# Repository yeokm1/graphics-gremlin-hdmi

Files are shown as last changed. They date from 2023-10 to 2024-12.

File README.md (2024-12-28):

# Graphics Gremlin HDMI

This is a modified version of the Graphics Gremlin ISA CGA/MDA graphics card to include a HDMI port. This is still based on the same Lattice ICE40HX4K FPGA.

(A production run has been made for this board. You can contact explit[at]mailbox[dot]org if you wish to purchase a unit.)

The latest revision now displays CGA colour 6 brown correctly. Since this project builds on the original project, it carries over some emulation inaccuracies in demos like 8088MPH and other applications.

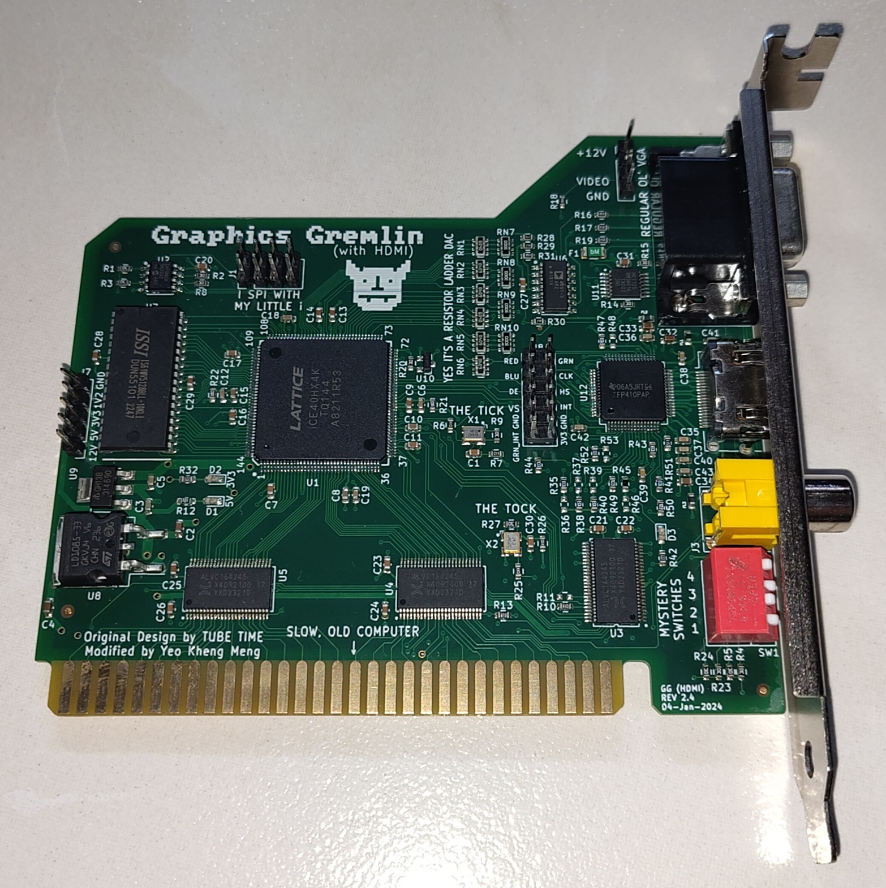
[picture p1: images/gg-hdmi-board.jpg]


Top view of board including the metal bracket.

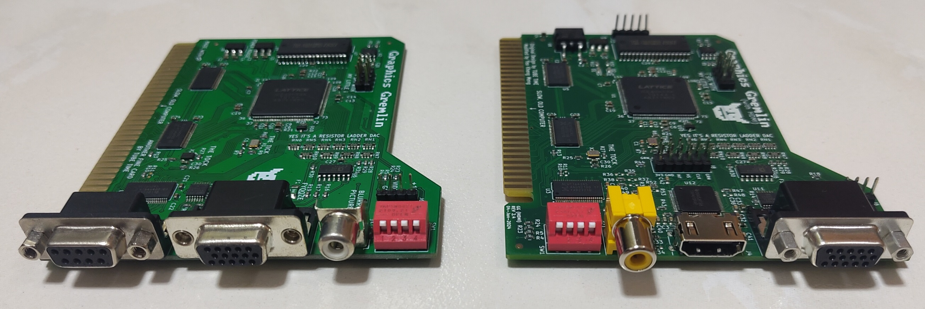
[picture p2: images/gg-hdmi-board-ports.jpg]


Left is the original Graphics Gremlin, right is my modified design.

# Demo videos

* Bootup and CGA compatibility tester (Brown fixed): https://www.youtube.com/watch?v=Ap-goSkkSUI
* Bootup and CGA compatibility tester (Deprecated): https://www.youtube.com/watch?v=xLy6on_o4YM
* 8088MPH: https://www.youtube.com/watch?v=WLpNmEhdTe4
* Area5150 (using CGA overscan): https://www.youtube.com/watch?v=9wYU6qMWlpE
* My talk on this project: https://www.youtube.com/watch?v=r_GiEIe_oZk

# Changes from original project

* Hardware changes
    * Added HDMI port by removing the RGBI DE9 port. Port positions adjusted to ease trace routing.
    * Added [TI TFP410](https://www.ti.com/product/TFP410) DVI transmitter (HDMI is compatible with DVI). HDMI is independent of the VGA/Composite output.
    * Test points for inputs to DVI transmitter.
    * Replaced the 3.3VDC 1A linear regulator with 3A as TFP410 is power hungry at up to 1A.
    * Added pin headers for power.
    * Added LED power indicators for 5V and 3.3V.
    * 2-layer -> 4-layer board to ease routing.
* HDL code changes
    * Selectable MDA colours (HDMI only)
    * Removed normal MDA bitstream as there is no more RGBI port.
    * Added CGA 70Hz mode.
    * Added CGA 60Hz overscan mode for demo and debug purposes.
    * Modified Scandoubler code to support Display Enable signal as required by DVI chip but not VGA.

Readme of the original Graphics Gremlin project can be found [here](original_README.md).

# How to replicate this board and use it?

1. [Fabrication guidelines](https://github.com/yeokm1/graphics-gremlin-hdmi/wiki/Fabrication-guidelines)

2. [Flashing FPGA bitstream](https://github.com/yeokm1/graphics-gremlin-hdmi/wiki/Flashing-bitstream)

3. [Testing the board](https://github.com/yeokm1/graphics-gremlin-hdmi/wiki/Testing-procedures)

4. Usage guide below:

# Switches position

## Switches 1 and 2 for MDA

These colours are applicable for the HDMI section only. 

| 1 | 2 | MDA colour |
|---|---|---|
| open | open | Green |
| open | closed | Yellow |
| closed | open | White |
| closed | closed | Red |



Sample of the different colours when testing the card on my [486 PC](https://github.com/yeokm1/retro-configs/tree/master/desktops/generic-486-pc).

## Switches 1 and 2 for CGA

| Switch | CGA |
|---|---|
| 1 | closed=composite mode. open=VGA mode |
| 2 | closed=thin font. open=normal font |

**Note that VGA and Composite cannot be used simultaneously.** No change from original Graphics Gremlin. HDMI will work on all modes.

## Switches 3 and 4

| 3 | 4 | Bitstream | Function |
|---|---|---|---|
| open | open | Bitstream 0 | MDA 70Hz |
| open | closed | Bitstream 1 | CGA 70Hz |
| closed | open | Bitstream 2 | CGA 60Hz |
| closed | closed | Bitstream 3 | CGA 60Hz with overscan |

### CGA 60 and 70Hz 
After internal scandoubling, the CGA 60Hz will produce a 640x400x60Hz output suitable for most VGA monitors. While this works for the HDMI LCD monitors I have tested, it is technically below the DVI specification of a minimum of 640x480x60Hz and 25.175Mhz pixel clock. 

To meet the specification in case some monitors insist, I have added another mode CGA 70Hz which will produce 640x400 at 70Hz. (Actually 71Hz due to precision limitations of clock multiplying) This 70Hz is however not compatible with composite displays including the one inside IBM5155.

### CGA 60Hz with overscan

The CGA overscan bitstream will show the overscan sections beyond the usual display area just short of Hsync and Vsync. Overscan is used in some demos like Area 5150. However not all HDMI monitors can accept this signal and/or display this properly.

I notice that while a monitor may initially accept this mode, tendency is it will randomly throw you display errors later.

**The purpose of this mode is just for debug and demo purposes**.

# Development info

## Directory structure

```
|-- fab: Gerbers, BOM and PDF schematic
|-- images: Images used in this repo
|-- isa-video: Kicad Design files
|-- verilog: Updated Verilog code to support HDMI
    | -- release: Bitstreams
|-- vga_display_status: Vivado project to process ICE40 FPGA output to DVI transmiter that runs on my Mimas A7 FPGA board.
|-- 3d-bracket: Step and STL file for a 3D-printable bracket
```

## Verilog Toolchain

To compile the project, I used the following open source tool-chain on my Ubuntu running on WSL on Windows 11.

```bash
sudo apt install libftdi-dev cmake

sudo apt install build-essential libboost-system-dev libboost-thread-dev libboost-program-options-dev libboost-test-dev libboost-filesystem-dev libboost-iostreams-dev libeigen3-dev

sudo apt install tclsh clang tcl-dev libreadline-dev bison flex

# Icestorm
git clone https://github.com/YosysHQ/icestorm.git icestorm
cd icestorm
make -j$(nproc)
sudo make install
cd ..

# NextPNR
git clone https://github.com/YosysHQ/nextpnr nextpnr
cd nextpnr
cmake -DARCH=ice40 -DCMAKE_INSTALL_PREFIX=/usr/local .
make -j$(nproc)
sudo make install
cd ..

# Yosys
git clone https://github.com/YosysHQ/yosys.git yosys
cd yosys
git submodule update --init
make -j$(nproc)
sudo make install
```

To program the bitstream to the board, I used `iceprog -p` from OSS CAD Suite. Follow the [flash instructions](https://github.com/yeokm1/graphics-gremlin-hdmi/wiki/Flashing-bitstream). 

## Code compilation

In my Ubuntu WSL:

```bash
cd verilog
mkdir build

# No CGA snow (default)
make

# With CGA snow
make DEFINES="-DCGA_SNOW=1"
```

```bash
# Program without CGA snow bitstream
iceprog -p release\isavideo-20240505-nosnow.binm

# Program with CGA snow bitstream
iceprog -p release\isavideo-20241229-withsnow.binm

# To see verbose output
iceprog -v -p isavideo.binm

# To suppress all output
iceprog -v -p isavideo.binm 2> nul
```

## Special handling for brown colour

The PCB and code treats the palette value "I:0 R:1 G:1 B:0" specially to produce a brown instead of dark yellow as per the CGA standard.

```verilog
// video[1] is the original green value
assign hdmi_grn = video[1] ^ (hdmi_red & video[1] & (hdmi_blu ^ 1) & (hdmi_int ^ 1));
assign hdmi_grn_int = hdmi_int ^ (hdmi_red & video[1] & (hdmi_blu ^ 1) & (hdmi_int ^ 1));
```

This is done using the above boolean logic to lower the green value by using the dedicated hdmi_green_int pin. This logic is [provided by @spbnick](https://github.com/yeokm1/yeokm1.github.io/discussions/115#discussioncomment-7022872).

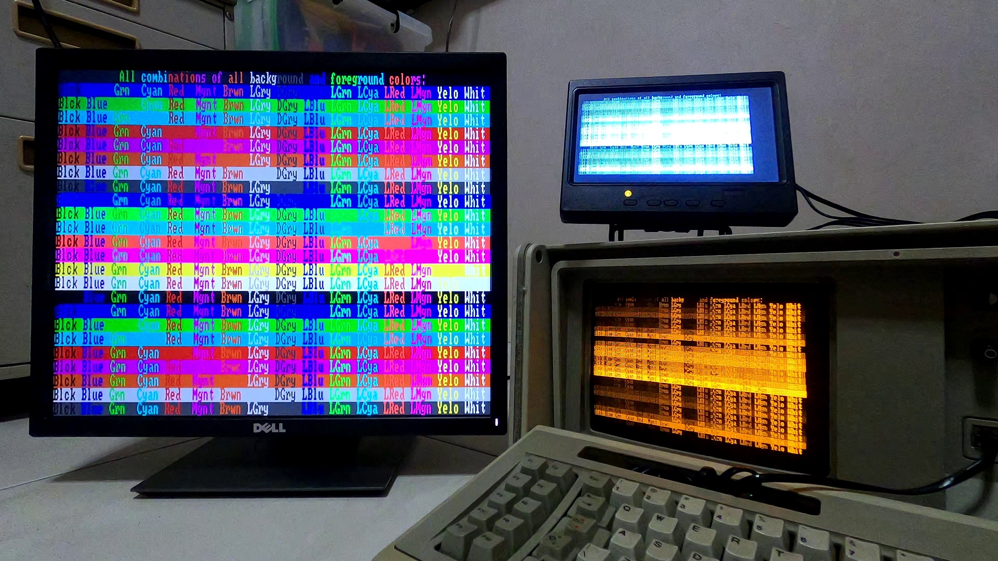
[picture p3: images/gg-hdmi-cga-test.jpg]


My IBM 5155 running the [CGA Compatibility Tester](https://github.com/MobyGamer/CGACompatibilityTester) displaying the colour palatte.

## Testing with Mimas A7 (Xilinx Artix 7)

As part of my testing, I also made a small FPGA test project using another FPGA board Mimas A7 based on the Xilinx Artix 7. 



The FPGA test board reads the raw RGBI, HS, VS, DE and CLK signals that are given to the DVI transmitter and displays the output using its own HDMI output.

The code is heavily based on the [HDMI_FPGA](https://github.com/dominic-meads/HDMI_FPGA/) project by Dominic Meads and runs on Vivado 2023.

## Bitstream Releases
* 20240505 - Disables CGA Snow (Recommended)
* 20241229 - Has CGA Snow. PC/XT systems which are overclocked with tools like [PC Sprint](https://github.com/reeshub/pc-sprint) should use this bitstream. This is due to the higher text mode data being clocked in which will cause artifacts if snow is totally avoided. More info in this [issue #5](https://github.com/yeokm1/graphics-gremlin-hdmi/issues/5).

## Hardware Releases

* 2.1 (9 Aug 2021): Initial release for GG (HDMI)
* 2.2 (17 Sept 2023): Extra Green control line for TFP410
* 2.3 (13 Oct 2023): Corrected VGA port footprint bug
* 2.4 (4 Jan 2024): Kicad 7.10, cleaned up schematic errors, removed unused traces, update pcb symbols and 3D models, cleaned up BOM. (No functional difference with 2.3)

## License
This work is licensed under a Creative Commons Attribution-ShareAlike 4.0
International License. See [https://creativecommons.org/licenses/by-sa/4.0/](https://creativecommons.org/licenses/by-sa/4.0/).

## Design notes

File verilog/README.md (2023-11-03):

# The Graphics Gremlin - FPGA code

(Click here for the [main README](https://github.com/schlae/graphics-gremlin/blob/main/README.md))

The FPGA code is divided into two major sets of files, those for CGA graphics and those for MDA graphics. At some point I'll tidy up and make a nice organized directory tree, but for now they're all in the same place.

* mda\_top.v: The top level file instantiating the MDA graphics logic (Not used as no more RGBI port)
* mda70\_top.v: An alternative top level file for VGA compatible MDA graphics
* mda.v: Implements MDA ISA interface, IO registers and instantiates the CRTC, SRAM interface, sequencer, and pixel engine
* crtc6845.v: This is my mostly-accurate recreation of the old Motorola 6845 CRT controller chip. It generates all the sync timings as well as the character and row addresses. There are probably slight differences between it and the real thing.
* mda\_sequencer.v: Controls timing across the entire card, deciding when to fetch SRAM data, look up character bits from the character ROM, and allow ISA bus access to the SRAM
* mda\_vram.v: Implements the state machine to arbitrate ISA bus and pixel engine access to the video ram (external SRAM)
* mda\_pixel.v: This is the pixel engine. It takes data coming from the SRAM, looks up the pixels in the character ROM, and shifts the data out one pixel at a time. 
* mda\_attrib.v: The attribute generator applies video attributes to the raw pixel data, including brightness, underline, inverse video, blinking. It also applies the blinking cursor.
* mda\_vgaport.v: This module turns the digital MDA video signals into numbers to drive the resistor ladder DAC connected to the VGA port. If you (gasp) dislike amber monochrome monitors, then you can hack this code to make it green or white.
* mda\_hdmiport.v: This module turns the digital MDA video signals to drive the DVI transmitter. Will also adjust the colour based on switch selection.

CGA graphics logic is similar to MDA and shares the same crtc6845.v logic, but the cards are different enough that I couldn't share more.
* cga\_top.v: Instantiates top level CGA logic with 60 Hz refresh rate.
* cga70\_top.v: Instantiates top level CGA logic with 70Hz refresh rate if higher pixel clock is required. (Composite displays are unlikely to work in this mode)
* cga\_overscan\_top.v: Instantiates top level CGA logic with 60Hz refresh rate and show overscan area. (Not all HDMI monitors can accept this)
* cga.v: Implements the ISA bus interface, CGA control registers, wait state generator, and most of the other CGA modules
* cga\_sequencer.v: Generates most of the timing signals used on the card, including memory fetches and pixel engine timing.
* cga\_vram.v: Implements a very basic address MUX for the SRAM interface. This actually causes too much CGA snow, and should be improved using the MDA VRAM interface as a model.
* cga\_pixel.v: The CGA pixel engine takes data from the SRAM, does a character lookup (text mode only), and shifts the data out 1 or 2 bits at a time, depending on the video mode.
* cga\_attrib.v: The attribute generator applies video attributes to the raw pixels data, including color, brightness, and blinking.
* cga\_composite.v: Contains the flip flops used to generate NTSC composite color as well as new sync pulses. The output is a 7-bit signal passed off to the green DAC channel for the RCA jack on the card.
* cga\_scandoubler.v: A very basic scan doubler to convert 15.7KHz CGA video to 31.4KHz VGA video. To save memory, this is done using 4-bit digital RGBI signals.
* cga\_vgaport.v: This module takes RGBI digital video from the scan doubler and turns it into numbers that drive the resistor ladder DAC connected to the VGA port. It produces CGA brown instead of dark yellow.
* cga\_hdmiport.v: This module takes RGBI digital video from the scan doubler to drive the DVI transmitter. It will produce Brown at CGA color #6 by controlling the dedicated Green intensity control pin.

Other miscellaneous files include:
* cga.hex and mda.hex: character ROM
* gremlin.pcf: The pin constraints file that determines what signals are tied to what pins on the FPGA
* isavideo\_t.v: A sloppy test bench that I used to validate and troubleshoot the rest of the logic.
* is61c5128\_t.v: A behavorial Verilog model of the SRAM chip.
* is61\_tester.v: A test bench I used to verify the SRAM chip behavioral model.

## Building

To build the project, you will need to install the tools from [Project IceStorm](http://www.clifford.at/icestorm/) (full instructions are available at that link). The Graphics Gremlin uses NextPNR, so make sure you install that.

Alternatively, you can install the [OSS Cad Suite](https://github.com/YosysHQ/oss-cad-suite-build) which is prebuilt and runs on a variety of platforms.

Once the tools are installed, just navigate to the Graphics Gremlin Verilog directory and run
```
mkdir build
make
```
If you have the FTDI programming cable hooked up to the card, you can also type `make prog`. As a convenience, `make reset` will not program the FPGA but will toggle its reset line which is useful if you change the red switch bank and don't want to cycle power on the host PC.

If the `make prog` command can't find the FTDI programming cable, make sure you have the udev rules set up.

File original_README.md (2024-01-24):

# The Graphics Gremlin - a Retro ISA Video Card

The Graphics Gremlin is an FPGA-based ISA video card specifically designed to emulate certain old video standards. This initial release emulates the original IBM PC monochrome graphics adapter (MDA) as well as the original IBM color graphics adapter (CGA). Since the logic is defined by the bitstream loaded into the FPGA, new emulations may be available in the future to support other video standards.

Graphics Gremlin PCB photo

But why emulate an old video card when they are still fairly easy to find online? Cards aren't hard to find, but monitors that can sync to the unusual frequencies used by MDA (18KHz) and CGA (15KHz) are much harder to find, and these frequencies are rarely supported by modern LCD monitors or video capture hardware.

For both MDA and CGA, the Graphics Gremlin has a VGA port that can deliver video running at standard (31KHz) frequencies that are well supported by LCD monitors, VGA-to-HDMI converters, and USB capture devices.

Here are the design files. The BOM includes Mouser Electronics parts numbers for everything except for the 0.1" headers which are typically cut to length anyway.

[Schematic](https://github.com/schlae/graphics-gremlin/blob/main/isavideo.pdf)

[Bill of Materials](https://github.com/schlae/graphics-gremlin/blob/main/isavideo.csv)

[Fab Files](https://github.com/schlae/graphics-gremlin/blob/main/fab/isavideo_rev2.zip)

## Fabrication and Assembly Notes

The circuit board is a 2-layer board, 4.19 x 3.74 inches (106 x 95mm). No special edge connector bevel is required, but you may want to specify at least ENIG plating. If you are rich then you could spend the extra money and get hard gold plated edge fingers. Order the boards with a fancy soldermask color so you can show off, or stick with a plain green to blend in.

You probably shouldn't attempt this project if you've never soldered surface mount components before. It'll lead to a lot of frustration and potentially damaged boards and parts.

There are two main methods you can use to assemble the board: reflow and hand soldering. Using the reflow method means that you'll need to order the solder stencil for the top side (there are no parts on the bottom of the board), and be sure to have fresh solder paste and some sort of vacuum pick-and-place tool. This method can be very quick but does require some skill and practice. 

Hand soldering is good when you only want to assemble a single board. This board has no BGA or leadless components which makes hand soldering possible. Some components have a very fine lead pitch (0.5mm) so only attempt this if you are comfortable with your soldering skills.

No matter which method you use, I recommend inspecting every solder joint very carefully under a microscope to make sure there are no solder bridges. If there are, clean them out with some solder braid.

Be careful not to mix up the two voltage regulators: they provide *different* voltages!

R11 should not be stuffed. By default this means that the 14.318MHz clock is generated on board. If you *move* R25 to R11, then the 14.318MHz clock comes from the ISA bus. The motherboard's 14.318MHz oscillator isn't always accurate enough for CGA color composite video.

Header J6 is optional. If you want to install it, remove pin 2 for keying.

Before plugging the card into a PC, it is wise to use a multimeter to verify that there are no short circuits between the +5V line (ISA bus pin B3) and ground or between the +12V line (ISA bus pin B9) and ground.

The card bracket may be fabricated from a plain, blank bracket such as a Keystone Electronics 9200. The dimensions are included in the KiCad file on the Dwgs.User layer. The best way to make holes in the bracket is by using a hand-operated sheet metal punch. A chassis nibbler is useful for making the DE-9 openings and the opening for the DIP switch bank.

You can also try 3D printing the bracket using the file below. There is a small line printed near the top which marks where you have to bend the bracket after you finish printing it. Use a hair dryer or a heat gun (on low) to soften it, and then bend it over a straightedge or ruler. For a slightly better finish on the outside of the bracket, flip it over in your slicer software so that the outside surface faces the bed of the printer.

[ISA bracket STL file](https://github.com/schlae/graphics-gremlin/blob/main/isabracket.stl)

## The FPGA
[A separate document discusses the Verilog code.](https://github.com/schlae/graphics-gremlin/blob/main/verilog/README.md)

Programming the FPGA is fairly easy and can be done with an FTDI FT2232H Mini Module [datasheet here](https://www.ftdichip.com/Support/Documents/DataSheets/Modules/DS_FT2232H_Mini_Module.pdf).

Wiring for the FT2232H mini module is as follows:

| Point 1 | Point 2 | Description |
| --- | --- | --- |
| CN2 pin 1  | CN2 pin 11 | V3V3 to VIO strap |
| CN3 pin 1  | CN3 pin 3 | VBUS to VCC strap |
| CN2 pin 3  | CN3 pin 12 | V3V3 to VIO strap (2) |
| CN2 pin 14  | SPI cable pin 1 | CS |
| CN2 pin 16  | SPI cable pin 2 | CDONE |
| CN2 pin 7 | SPI cable pin 3 | SCK (serial clock) |
| CN2 pin 15  | SPI cable pin 4 | CRESET |
| CN2 pin 9 | SPI cable pin 5 | CIPO (controller in, peripheral out) |
| CN2 pin 2 | SPI cable pin 6 | GND |
| CN2 pin 10  | SPI cable pin 7 | COPI (controller out, peripheral in) |
| n/a | SPI cable pin 8 | not used |

To program the FPGA, power needs to be applied. The simplest way to do this is to drop it in a nearby PC and turn it on. With the cable plugged in to a USB port, you can use the [Project IceStorm](http://www.clifford.at/icestorm/) tool "iceprog" to program the SPI flash memory.

`iceprog -p isavideo.binm`

Once the SPI flash has been programmed, iceprog toggles the reset line so that the FPGA loads the new bitstream. At this point it will be active on the ISA bus, but the PC's BIOS doesn't know about it. Reboot the computer and it should find it.

Note that leaving the programming cable plugged in can sometimes cause issues with the FPGA being held in reset when the PC powers up. In that case, simply unplug the cable and reboot the PC.

### Windows Instructions
Thanks to [midicdj1000](https://github.com/midicdj1000), here are some instructions for programming the FPGA using Windows.

1. Download and extract the Windows build of the [OSS CAD Suite](https://github.com/YosysHQ/oss-cad-suite-build/releases).
2. Connect the FT2232H mini module according to the directions in the previous section.
3. Install the [FTDI driver](https://ftdichip.com/drivers/).
4. Change the driver to libusbK using these [instructions](https://learn.adafruit.com/adafruit-ft232h-breakout/windows-setup).
5. From the command line in the Bin folder of the OSS-CAD-Suite folder, run `iceprog -p isavideo.binm`. (Be sure to include the appropriate path to the isavideo.binm file, or simply copy the file into the Bin folder.)

## The Red Switch Bank

The red switch bank on the top right of the card controls two things: the bitstream selected by the FPGA when it powers up and specific settings for the selected bitstream.

The bitstream is selected using switches 3 and 4:

| 3 | 4 | Description  | Default |
| --- | --- | --- | --- |
| open | open | Bitstream 0  | MDA (VGA compatible signal) |
| open | closed | Bitstream 1  | MDA (MDA monitors only) |
| closed | open | Bitstream 2  | CGA (both VGA and CGA compatible signals) |
| closed | closed | Bitstream 3  | Not used |

For example, if you want to use MDA with a VGA monitor, set switches 3 and 4
to the open (up) position. (CGA has support for both VGA and CGA monitors built in since it implements a line doubler.)

The remaining two switches have a function that is bitstream-dependent.

| Switch | MDA (VGA comp.) | MDA | CGA |
| --- | --- | --- | --- |
| 1 | Not used | Not used | closed=composite mode. open=VGA mode |
| 2 | Not used | Not used | closed=thin font. open=normal font |

## Connectors

The Graphics Gremlin provides both a 9-pin RGBI connector and a 15-pin VGA connector. The 9-pin connector is designed for use with digital monitors such as the IBM 5151, 5153, or a variety of older multisync monitors.

The RCA jack is used for CGA composite video when that bitstream is selected (see the previous section). Note that the signal for the RCA jack is also used as the green channel for the VGA connector so they cannot both be used at the same time.

Connector J6 is for compatibility with IBM CGA cards which provide the composite signal for RF modulators. This connector is really only useful if you want to use the card with an IBM 5155 Portable PC (the internal monitor has a cable that plugs into this connector).

## Troubleshooting

This is a complex card with many fine-pitch components, so most likely any issues you run into will be caused by a solder bridge or broken connection. Go back and check each solder joint using a microscope. Make sure you didn't install any chips or the clock oscillators the wrong way around.

A few things to confirm for basic operation include:

1. Are the 3.3V and 1.2V regulators putting out those voltages?
2. Are the two clock oscillators generating 10MHz and 14.318MHz?
3. Can the SPI flash get programmed by the FTDI board *and verified?*

Unlike the namesake video cards of old, the FPGA comes up with the internal card registers fully programmed and the card should generate video even if the ISA bus interface isn't working at all. A simple check involves configuring the switch bank for CGA and confirming that it produces a video signal. You can even flip to composite mode to make sure that works as well.

Checking these first can help you narrow down the source of the problem.

To confirm proper operation on the ISA bus, it's helpful to set up a PC with a VGA card (or CGA card) and the Graphics Gremlin configured for MDA. These can coexist on the same PC.

Boot up the PC and run the DOS DEBUG program. Then see if you can access the CRTC registers. Unlike the original MDA card, these can be read back. Note: if you use the VGA compatible MDA mode, then these registers cannot be written to.

```
o 3b4 0
i 3b5
```

This should return a number that is not 0 or FF. (The exact number depends on which MDA bitstream you are using).

If that works, then check to see if you can read and write the MDA video memory area:

`e b000:0000 55 aa 55 aa`...

and to check what you just wrote

`d b000:0000`

This will exercise the connections to the SRAM.

Other strange things that can happen:
* If the PC just beeps out an error code during startup, check for motherboard jumpers or switches that have to be set. You might also try a dual video card setup with a VGA card.
* If the PC never boots at all, it could be that the IO\_READY pin (A10) on the ISA bus is stuck low. Also check for any short circuits on the address, data, or control lines.
* If the PC power supply refuses to start or if there is smoke, then you probably have a short circuit on the +5V or +12V line on the card. Check for things like solder paste smeared underneath capacitors or traces shorted to the ground plane.

In general, use a logical process of elimination to find where the fault (or faults!) lurks.

## Emulation Accuracy

The logic for both the MDA and CGA cards is as close as I could get it to match the schematics available in the technical reference manuals, with two exceptions. The VRAM interface is specific to the 8-bit SRAM chip that I am using instead of the 16-bit SRAM on the original MDA or the 16-bit DRAM used on the CGA, so it had to be quite different from the originals. As a result, the sequencer state machine had to be designed from scratch. There are some other minor differences mostly to support the nonstandard VGA-compatible signal outputs.

Accuracy is a work in progress. Certain demos, like 8088MPH, that require cycle-accurate operation on a 4.77MHz PC, don't work 100% correctly. The causes of this aren't yet fully understood.

## Future Plans

Although the card supports just MDA and CGA, I'd like to support other video standards in the future. EGA and even VGA would be nice, but there are two huge challenges associated with that: they use custom gate array chips and they also use a 32-bit memory bus. This means I would need to quadruple the pixel clock to produce four 8-bit fetches from the SRAM. Due to this bus bandwidth limitation, Super VGAs are totally off the table.

Other people have requested support for Hercules, Tandy, and PCjr graphics, which I might get around to implementing someday.

There are also some neat non-graphics uses for the card. With some clever programming, the card could be turned into a memory card to extend the RAM in some of the older IBM PC and XT machines (XMS RAM). It could also emulate an expanded memory card for machines that can't run EMM386. BIOS extension ROMs stored in the NOR flash chip could also be mapped to ROM areas in the PC memory map, which might also be useful.

The card could act as a fancy POST card, perhaps even with a mini bus analyzer built in (using a connected VGA monitor).

It's even theoretically possible to implement a sound card using the composite video jack (and 7-bit resistor DAC) as the sound output.

## License
This work is licensed under a Creative Commons Attribution-ShareAlike 4.0
International License. See [https://creativecommons.org/licenses/by-sa/4.0/](https://creativecommons.org/licenses/by-sa/4.0/).

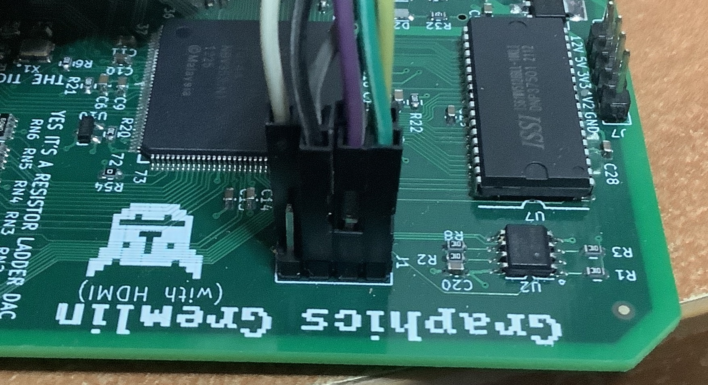
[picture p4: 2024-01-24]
images/gg-hdmi-board-prog-pin-back.jpg

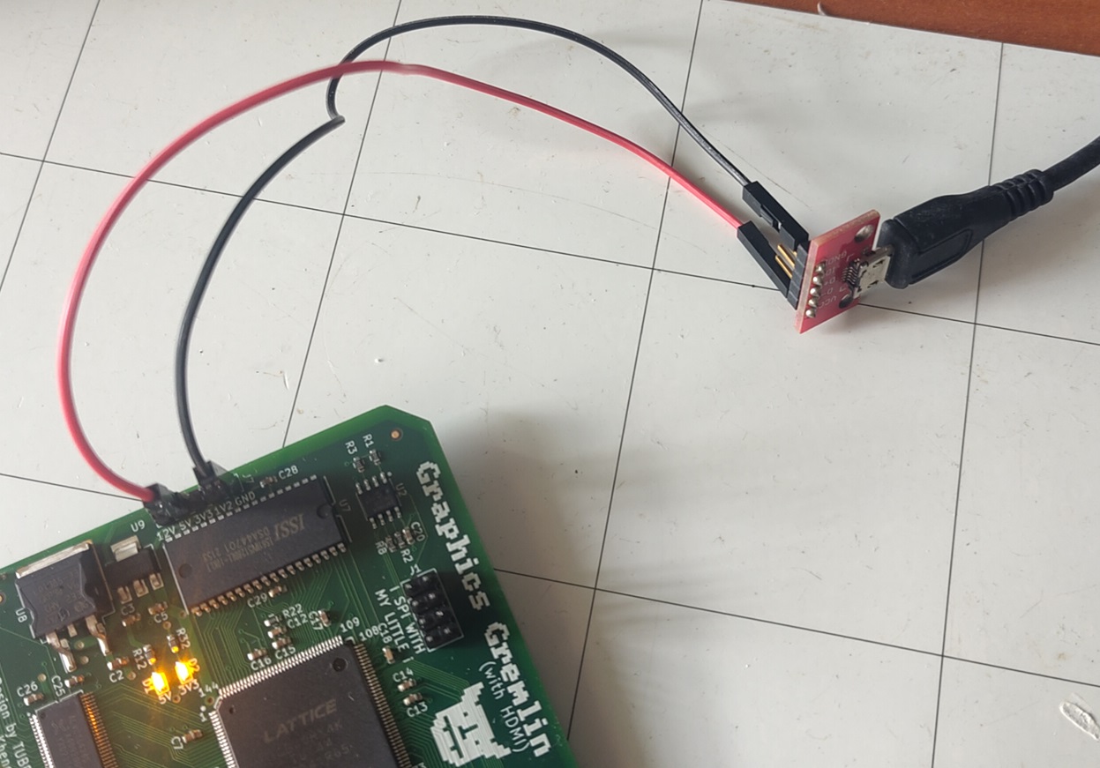
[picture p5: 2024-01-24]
images/gg-hdmi-prog-5v.jpg

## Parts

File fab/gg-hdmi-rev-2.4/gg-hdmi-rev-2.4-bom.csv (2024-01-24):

Item | Qty | Designator | Comment | Footprint | Mouser | Non-Mouser Part Number
1 | 23 | C1, C7, C8, C9, C10, C11, C13, C14, C15, C16, C17, C20, C21, C22, C23, C24, C25, C26, C27, C28, C29, C30, C31 | 1u | Capacitor_SMD:C_0603_1608Metric | 810-CGA3E1X7R1C105AC
2 | 2 | C2, C4 | 10uF 16V | Capacitor_SMD:C_0603_1608Metric_Pad1.08x0.95mm_HandSolder | 81-ZRB18AR61C106ME1L
3 | 6 | C3, C5, C6, C12, C18, C19 | 4.7u | Capacitor_SMD:C_0603_1608Metric | 187-CL10A475KP8NNNC
4 | 3 | C32, C33, C34 | 10uF 16V | Capacitor_SMD:C_0603_1608Metric | 81-ZRB18AR61C106ME1L
5 | 9 | C35, C36, C37, C38, C39, C40, C41, C42, C43 | 0.1uF | Capacitor_SMD:C_0603_1608Metric | 581-060316C104K
6 | 2 | D1, D2 | Yellow | LED_SMD:LED_0603_1608Metric_Pad1.05x0.95mm_HandSolder | 78-TLMY1100
7 | 1 | D3 | Green | LED_SMD:LED_0603_1608Metric_Pad1.05x0.95mm_HandSolder | 78-TLMG1100
8 | 1 | F1 | 1A | Resistor_SMD:R_1206_3216Metric | 530-0ZCJ0050FF2G
9 | 3 | FID1, FID2, FID3 | Fiducial | Fiducials:Fiducial_1mm_Dia_2mm_Outer | DNP
10 | 3 | FL1, FL2, FL3 | BLM18RK601SN1D | libraries:BEADC1608X95N | 81-BLM18RK601SN1
11 | 1 | J1 | PROG | Connector_PinHeader_2.54mm:PinHeader_2x04_P2.54mm_Vertical |  | PZ254-2-04-Z-8.5
12 | 1 | J2 | DB15_Female_HighDensity_MountingHoles | Connector_Dsub:DSUB-15-HD_Female_Horizontal_P2.29x1.98mm_EdgePinOffset8.35mm_Housed_MountingHolesOffset10.89mm | 156-3315-E
13 | 1 | J3 | PJRAN1X1U04X | libraries:SWITCHCRAFT_PJRAN1X1U04X | 502-PJRAN1X1U04X
14 | 1 | J4 | 10029449-111RLF | libraries:HDMI_A_Amphenol_10029449-111 | 649-10029449-111RLF
15 | 1 | J5 | DNP | Conn:BUS_PC_8BIT | DNP
16 | 1 | J6 | RFMOD | Connector_PinHeader_2.54mm:PinHeader_1x04_P2.54mm_Vertical |  | PZ254-1-04-Z-8.5
17 | 1 | J7 | Conn_01x05 | Connector_PinHeader_2.54mm:PinHeader_1x05_P2.54mm_Vertical |  | PZ254-1-05-Z-8.5
18 | 1 | J8 | Conn_02x06_Odd_Even | Connector_PinHeader_2.54mm:PinHeader_2x06_P2.54mm_Vertical |  | PZ254-2-06-Z-8.5
19 | 13 | R1, R2, R3, R4, R5, R8, R9, R14, R15, R20, R23, R24, R27 | 10K | Passive:RESC1608X55 | 603-RC0603FR-0710KL
20 | 5 | R6, R7, R10, R25, R26 | 10 | Passive:RESC1608X55 | 603-RC0603FR-0710RL
21 | 1 | R11 | DNP | Passive:RESC1608X55 | DNP
22 | 1 | R12 | 2200 | Resistor_SMD:R_0603_1608Metric_Pad0.98x0.95mm_HandSolder | 603-RC0603FR-072K2L
23 | 1 | R13 | 1K | Passive:RESC1608X55 | 603-RC0603FR-071KL
24 | 5 | R16, R17, R18, R19, R31 | 75 | Passive:RESC1608X55 | 603-RC0603FR-0775RL
25 | 2 | R21, R22 | 100 | Passive:RESC1608X55 | 603-RC0603FR-07100RL
26 | 3 | R28, R29, R30 | 237 | Passive:RESC1608X55 | 603-RC0603FR-07237RL
27 | 2 | R32, R42 | 1200 | Resistor_SMD:R_0603_1608Metric | 603-RC0603FR-101K2L
28 | 1 | R33 | 0 | Resistor_SMD:R_0603_1608Metric | 603-RC0603FR-070RL
29 | 7 | R34, R36, R37, R39, R46, R48, R53 | DNP | Resistor_SMD:R_0603_1608Metric | DNP
30 | 9 | R35, R38, R40, R41, R43, R44, R47, R49, R50 | 10k | Resistor_SMD:R_0603_1608Metric | RC0603JR-0710KL
31 | 1 | R45 | 5k | Resistor_SMD:R_0603_1608Metric | 603-RT0603BRE075KL
32 | 1 | R51 | 510 | Resistor_SMD:R_0603_1608Metric | 603-RC0603JR-07510RL
33 | 1 | R52 | 33k | Resistor_SMD:R_0603_1608Metric | 603-RC0603FR-1033KL
34 | 6 | RN1, RN2, RN3, RN4, RN5, RN6 | 604 | Passive:RESCAV80P320X160X70-8 | 652-CAY16-6040F4LF
35 | 4 | RN7, RN8, RN9, RN10 | 300 | Passive:RESCAV80P320X160X70-8 | 652-CAY16-3000F4LF
36 | 1 | SW1 | SW_DIP_x04 | Switch:SW_DIP254P762X635-8 | 706-76PSB04ST
37 | 1 | U1 | ICE40HX4K-TQ144 | Active:TSQFP50P2200X2200X160-144 | 842-ICE40HX4K-TQ144
38 | 1 | U2 | SST26VF080A-104I/SN | Active:SOP127P620X175-8 | 579-26VF080A-104I/SN
39 | 3 | U3, U4, U5 | 74ALVC164245 | Active:TSSOP50P810X120-48 | 771-74ALVC164245
40 | 1 | U6 | ADA4891-3 | Active:SOP127P620X175-14 | 584-ADA4891-3ARZ
41 | 1 | U7 | IS61WV5128BLL-10KLI | Active:SOJ127P1118X376-36 | 870-61WV5128B10KLI
42 | 1 | U8 | LD1085D2T33R | Package_TO_SOT_SMD:TO-263-2 | 511-LD1085D2T33-TR
43 | 1 | U9 | AP2114HA-1.2 | Active:SOT230P700X170-3 | 621-AP2114HA-1.2TRG1
44 | 1 | U10 | APX803S00-29SA-7 | Active:SOT95P230X117-3 | 621-APX803S00-29SA-7
45 | 1 | U11 | 74HCT125 | Active:TSOP65P640X110-14 | 771-74HCT125PW-T
46 | 1 | U12 | TFP410PAP | Package_QFP:HTQFP-64-1EP_10x10mm_P0.5mm_EP8x8mm_Mask4.4x4.4mm_ThermalVias | 595-TFP410PAP
47 | 1 | X1 | 10MHz | Passive:XTAL320X250X120-4 | 520-ECS-2333-100-BNT
48 | 1 | X2 | 14.318MHz | Passive:XTAL320X250X120-4 | 815-ASE-14.318MLCT
49 | 2 | - | Jack screw for VGA port | UNC 4#40 | 710-94511000

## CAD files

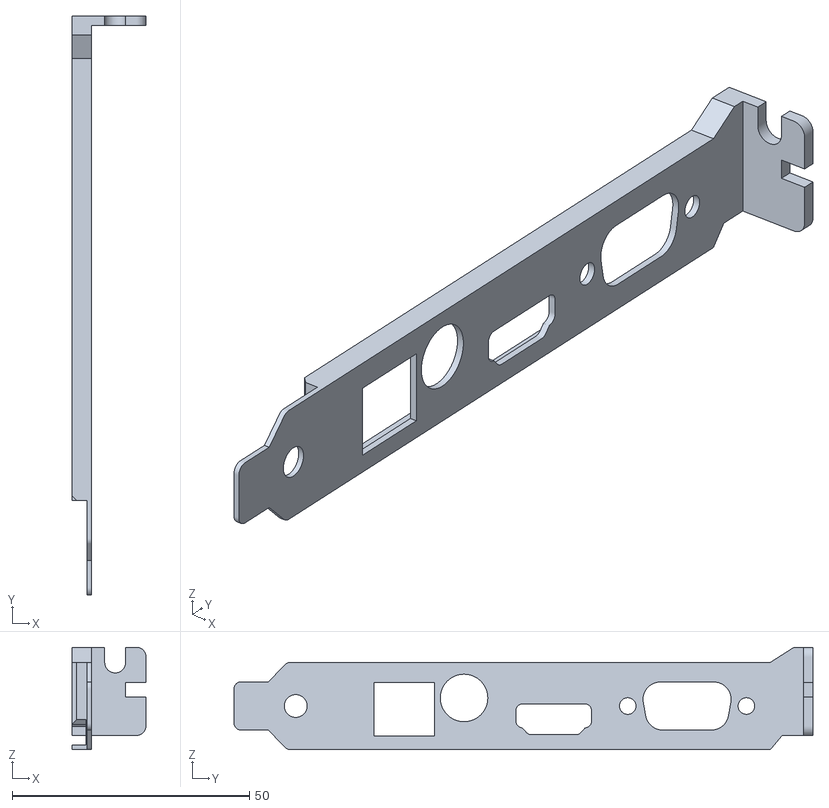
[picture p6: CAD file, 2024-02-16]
3d-bracket/gg-hdmi-3d-bracket.stl
15.6 x 122.0 x 21.6

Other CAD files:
3d-bracket/gg-hdmi-bracket.step

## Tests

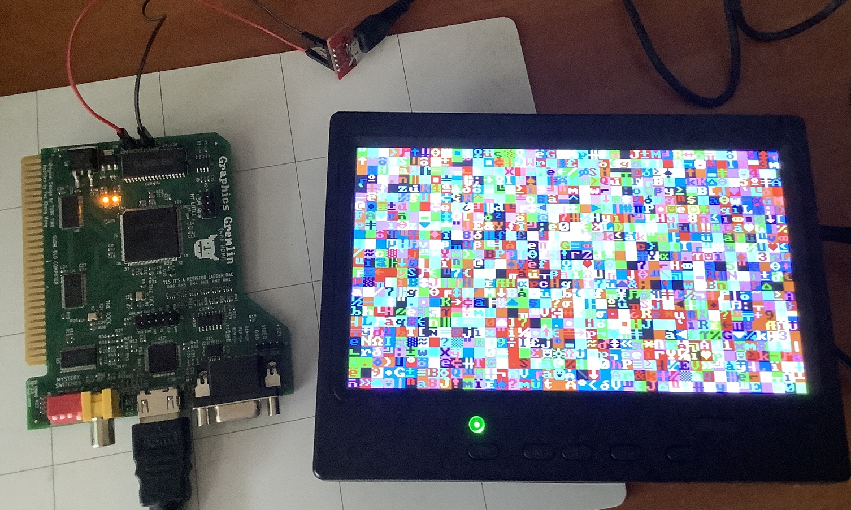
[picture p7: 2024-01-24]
images/gg-hdmi-test-cga70-hdmi-small.jpg

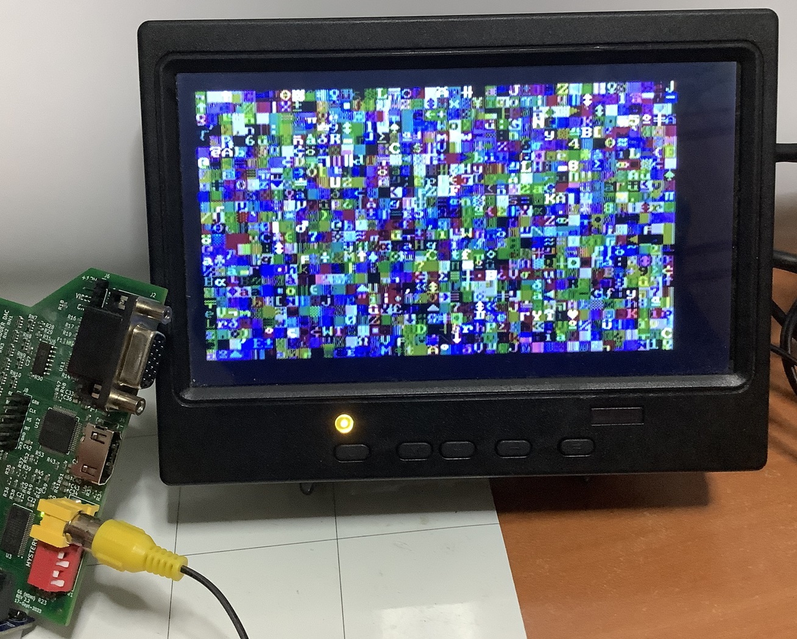
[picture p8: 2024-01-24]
images/gg-hdmi-test-cga-comp-normal.jpg

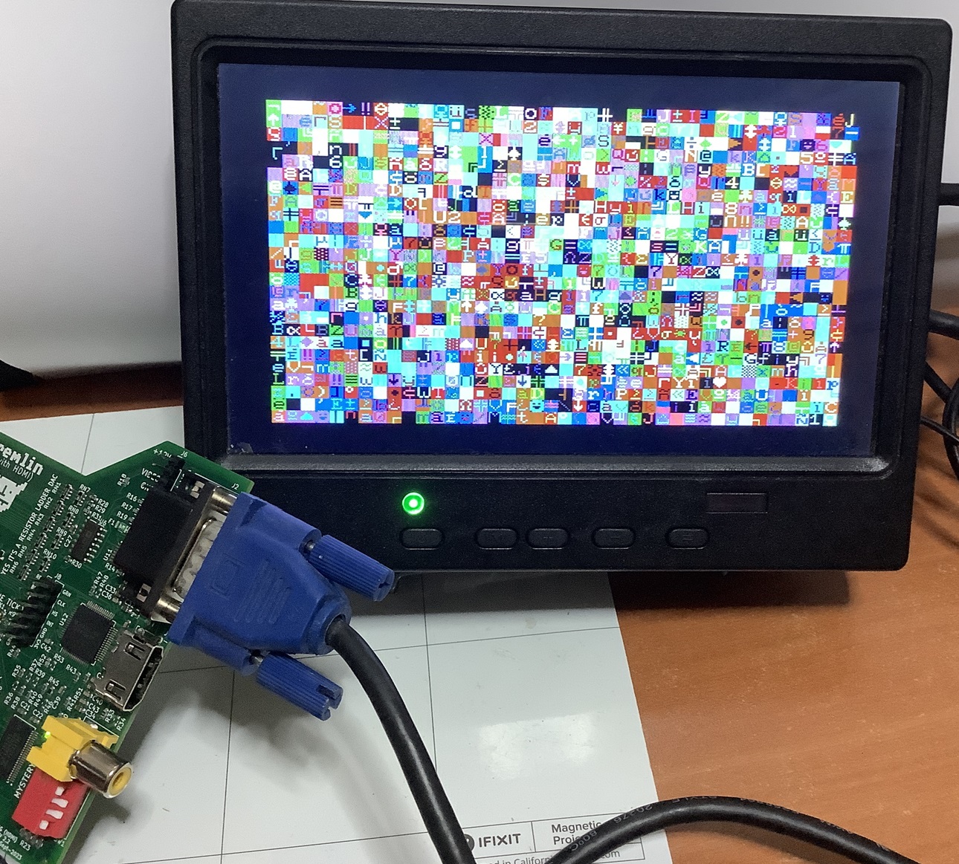
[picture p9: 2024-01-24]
images/gg-hdmi-test-cga-vga-thin.jpg

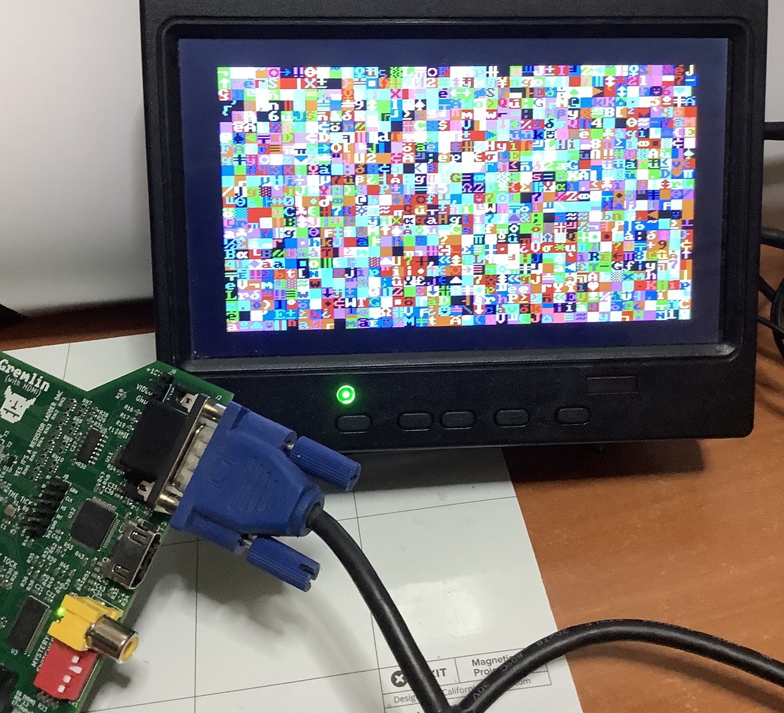
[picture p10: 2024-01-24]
images/gg-hdmi-test-cga-vga-normal.jpg

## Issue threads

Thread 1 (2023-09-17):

Issue with brown

yeokm1, 2023-09-17:
The CGA colour palette specifies that colour 6 is supposed to be Brown but is shown as Dark Yellow.

I may have a possible idea how to fix this by treating the Green intensity value differently as I found a possible FPGA pin I can spare.

Upcoming changes in this branch: https://github.com/yeokm1/graphics-gremlin-hdmi/tree/solve-brown

yeokm1, 2023-09-17:
Green has its dedicated Intensity control pin which can be controlled directly from the FPGA. A spare pin was found by not having the FPGA needing to control the PD pin of the DVI transmitter. DVI PD pin can be left permanently on.

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

yeokm1, 2023-09-17:
PCB board layout is completed. Sending for fabrication and assembly soon.

One of the "Pmod" header pins 3V3 has been replaced to serve as a test point for GRN_INT.

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

yeokm1, 2023-09-19:
PCB has been sent for respin and assembly. Will take a month or so. Fingers crossed.

Closed 2023-10-13.

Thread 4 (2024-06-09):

Problem with Flashing

explit7, 2024-06-09:
Hello @yeokm1 - Sorry for opening issue in your Repo and not in the TubeTime Repo, maybe you can answer my question.
Its about original GG. Your GG HDMI is in Production, so i dont tried it yet.

I flash with a little bit different UM-FT2232H Module, because its much cheaper in Germany.
The Problem which i have are the missing 3 Pins
V3V3 to VIO strap
VBUS to VCC strap
V3V3 to VIO strap (2)
which are not there on my UM-FT2232H Module

I already posted a question in the original GG Repo:
https://github.com/schlae/graphics-gremlin/issues/22

To my Problem:

I could flash 2 cards without this 3 PINs - anything was fine.
Now, it flashes without errors, but at the End i get a Message that Flash and File are different.
When i try the card - it doesn't work. Somehow the Flash ROM is messed.

Maybe you have some Ideas with:

- what to do with 3 missing pins
- how to solve the flashing problem
- 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

Thank you very much!

yeokm1, 2024-06-10:
May I ask if you have powered on the card in addition to connecting the programming header?

For the original GG, you have to power the card via a PC with an ISA slot. For the GG HDMI, using a PC for power is not mandatory as I added 5V supply header which you can power the card from.

Without power, the FT2232 will just blindly write to SPI output but you will find problems reading back the flash.

Perhaps you can take a photo of your flashing setup including the GG?

I'm not familiar with UM-FT2232H Module.

- VBUS to VCC supplies power to the voltage regulators that supplies to FT2232.

- V3V3 to VIO strap and V3V3 to VIO strap (2) is just to supply power to the FT2232's input/output section.

If the UM-FT2232H module has strapped them all internally for you, then you don't have to do anything. Perhaps

explit7, 2024-06-10:
Thank you very much for fast answer, @yeokm1 !
Of course i flash the card, when its in my Micro8088 PC and the PC is on. Otherwise it would not get 5V over ISA.
As i said, the first 2 times i flashed without no Problems.
I am afraid, that i somehow programmed the FPGA with 5V instead of 3.3V and now the flash is corrupted.

I think the best idea would be to buy the real FT2232 and try it again...

Another question: Do you plan make your software improvements for the GG HDMI also available for the normal GG?
Thanks

yeokm1, 2024-06-10:
It is indeed true that the FPGA and flash memory are not 5V tolerant. If you somehow use 5V to do so, then yes something could be damaged. Another thing could be ESD.

This video might be interesting for you. He suggests (in comments) to use Adafruit FT232H breakout board to avoid flashing software problems. https://www.youtube.com/watch?v=ywzjZvqpQcI

One way to help troubleshoot the issue is to see if you can read out the flash serial number. Go to 09:10 of his video.

If all else fails, then no choice but to get the original FT2232 mini module and try it.

The logic changes I have made to to the GG HDMI are strictly to support the HDMI section. Not transferrable to the original GG.

explit7, 2024-06-14:
I close the issue, it was a problem with my wiring. some of the cables has bad connection. Thanks for Help!

Closed 2024-06-14.

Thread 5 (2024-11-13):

CGA visual artifacts on overclocked CPU

yeokm1, 2024-11-13:
Observations:

When system is overclocked, visual artifacts appear as shown in this video.

https://github.com/user-attachments/assets/a5e70743-c081-44d0-be6c-dd7d4c9eae9d

IBM5155 CRT on CGA

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

External HDMI monitor

Actions to simulate the problem:

1. Install [PC Sprint](https://github.com/reeshub/pc-sprint) into a PC/XT system with CPU capable of higher clock speeds like Intel 8088-2 and NEC V20.
2. On normal mode, the graphics card works properly.
3. When overclock is enabled on PC Sprint, the artifacts appear in CGA text mode.

This issue was first reported by @Maillouski

MDA and CGA graphics mode seems to be unaffected.

yeokm1, 2024-12-23:
The problem can be replicated on a Book8088 set to Turbo mode to overclock the CPU.

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

From initial troubleshooting with an oscilloscope, the overclocked CPU transmits the text on the ISA bus far faster than expected. On other more modern ISA systems even like 486-based, those motherboards still adhere properly to the original CGA standard by writing text as per the original CGA speed on the ISA bus.

The entire Gremlin card in CGA mode runs on a standard clock. So the faster transmissions may not all "captured" by the card. This problem tends to happen more on full screen refreshes as more text data is changed unlike when you type a command letter by letter.

As for why graphics mode is not affected, base on initial reading of the original Gremlin's Verilog code, pixel data is directly written to VRAM bypassing a lot of the clock circuitry. (Not to say graphics mode totally won't be affected, just that likelihood is less.) For text mode, a lot of clocked code is required to parse the attributes and character code, ROM etc to convert them to pixels.

MDA is less affected because it's running at a high clock to make it compatible with VGA and HDMI. It's refresh rate in the Gremlin HD is 70Hz. This is ok as MDA does not use NTSC Composite and thus no need to adhere to its limitations which CGA has to. (If the Gremlin HD was using 50Hz refresh as per the original MDA standard, it will be affected).

To fix this problem, I will have to decouple the ISA writing to VRAM and the reading/video generation. This is not a straight forward matter as I have to separate sections of this 2 clock domains and cross them properly. Currently all the code is sharing the same clock. **I'm still thinking on how to approach this as it will require same significant rearchitecting.**

I cannot just straight up increase the clock as this will affect all the video outputs especially the Composite (and CRT) which strictly adheres to NTSC.

yeokm1, 2024-12-28:
The root cause was further narrowed down to the logic being used to avoid CGA snow in VRAM writes. To avoid CGA snow, a VRAM arbitration logic was used to "decide" between VRAM writing to ISA bus and VRAM reading for display purposes.

With an overclocked CPU, the VRAM writing rate is increased and competes more with the reading time and some data will fail to be written into VRAM. To resolve this, we revert to disable the CGA avoidance arbitration logic where the ISA graphics data will just write through to the VRAM regardless. The tradeoff is that CGA snow will return.

A new bitstream is provided in the release folder if this particular need is required.

Closed 2024-12-28.

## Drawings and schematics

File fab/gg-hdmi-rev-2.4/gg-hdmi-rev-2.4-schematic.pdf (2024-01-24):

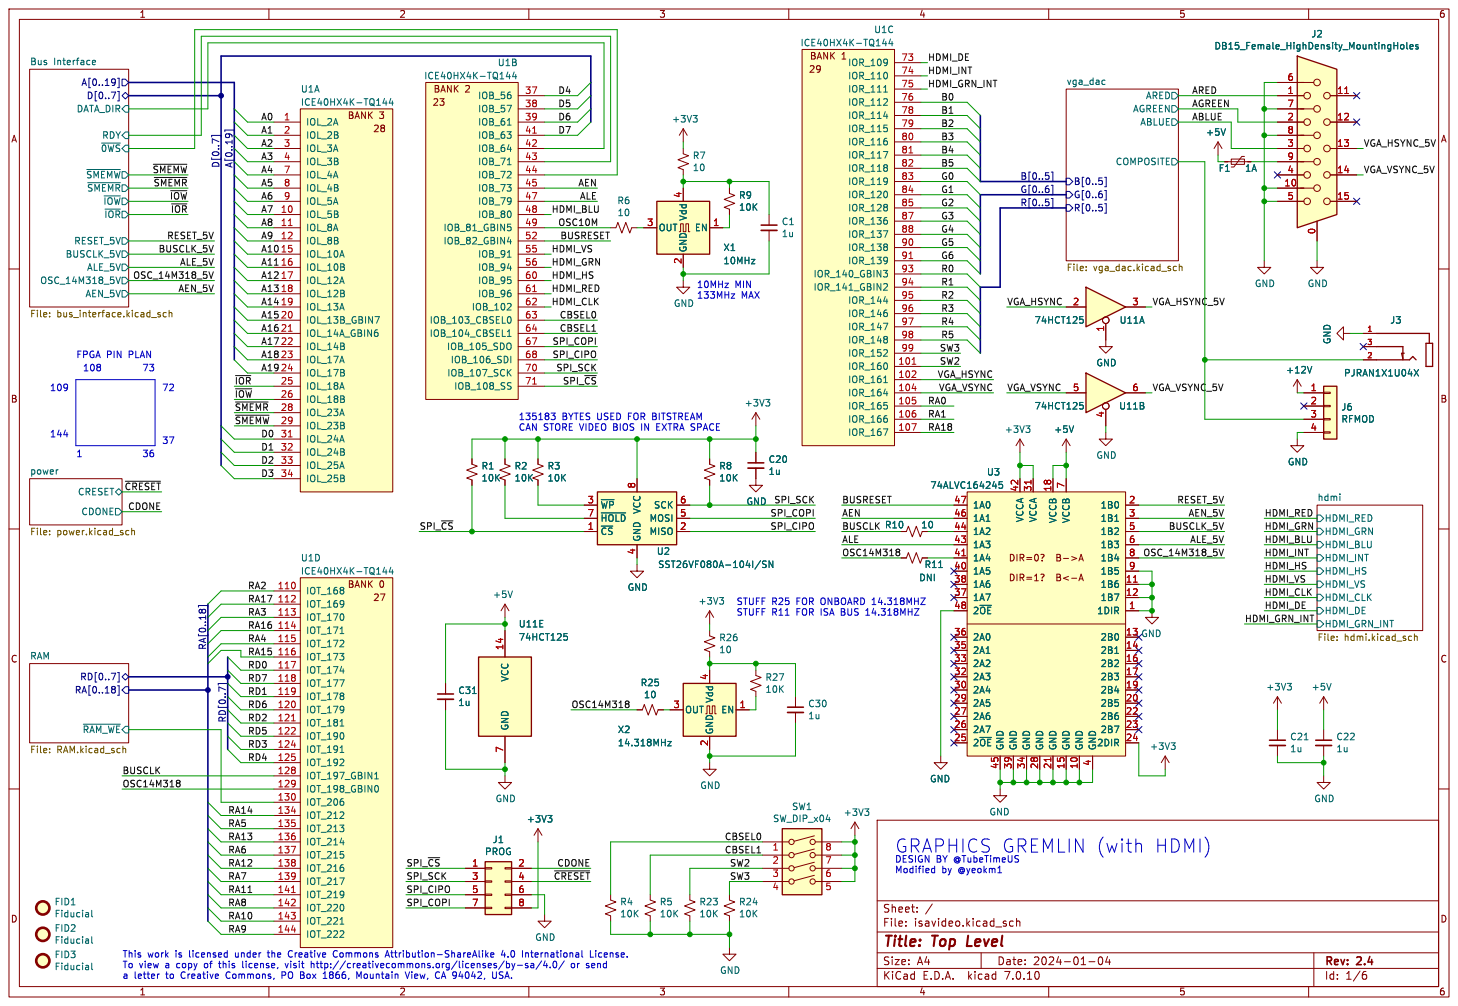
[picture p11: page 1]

File: RAM.kicad_sch CDONE CRESET

4 MOSI 5 SCK 6 ~{HOLD} 7 VCC

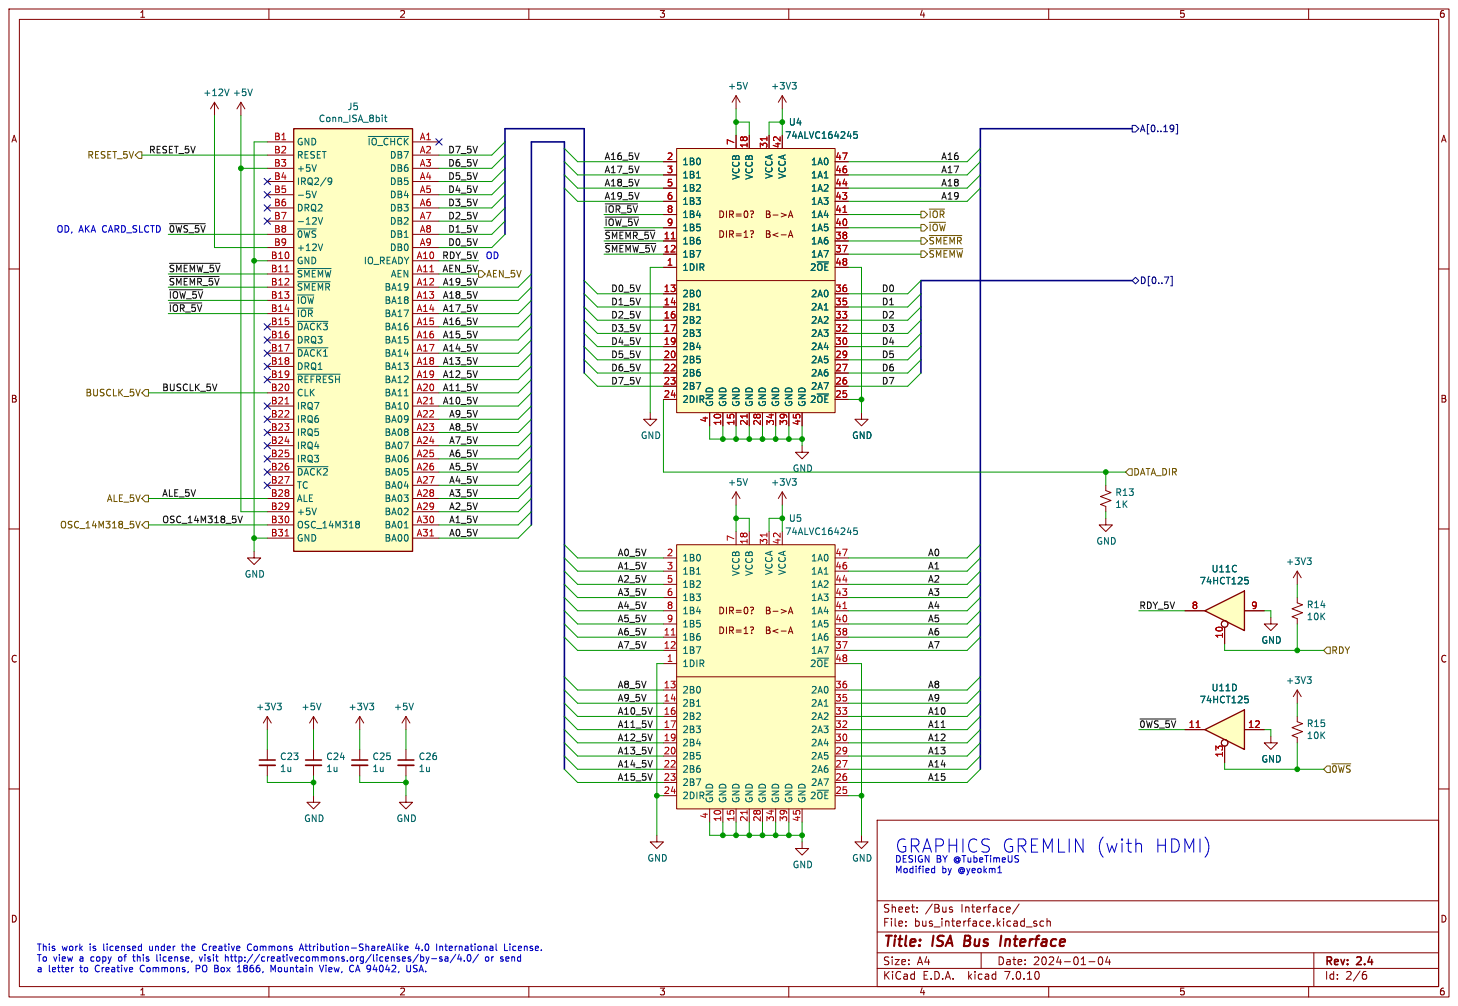
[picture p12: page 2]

GRAPHICS GREMLIN (with HDMI)
DESIGN BY @TubeTimeUS Modified by @yeokm1

Id: 2/6 Title: ISA Bus Interface

a letter to Creative Commons, PO Box 1866, Mountain View, CA 94042, USA.

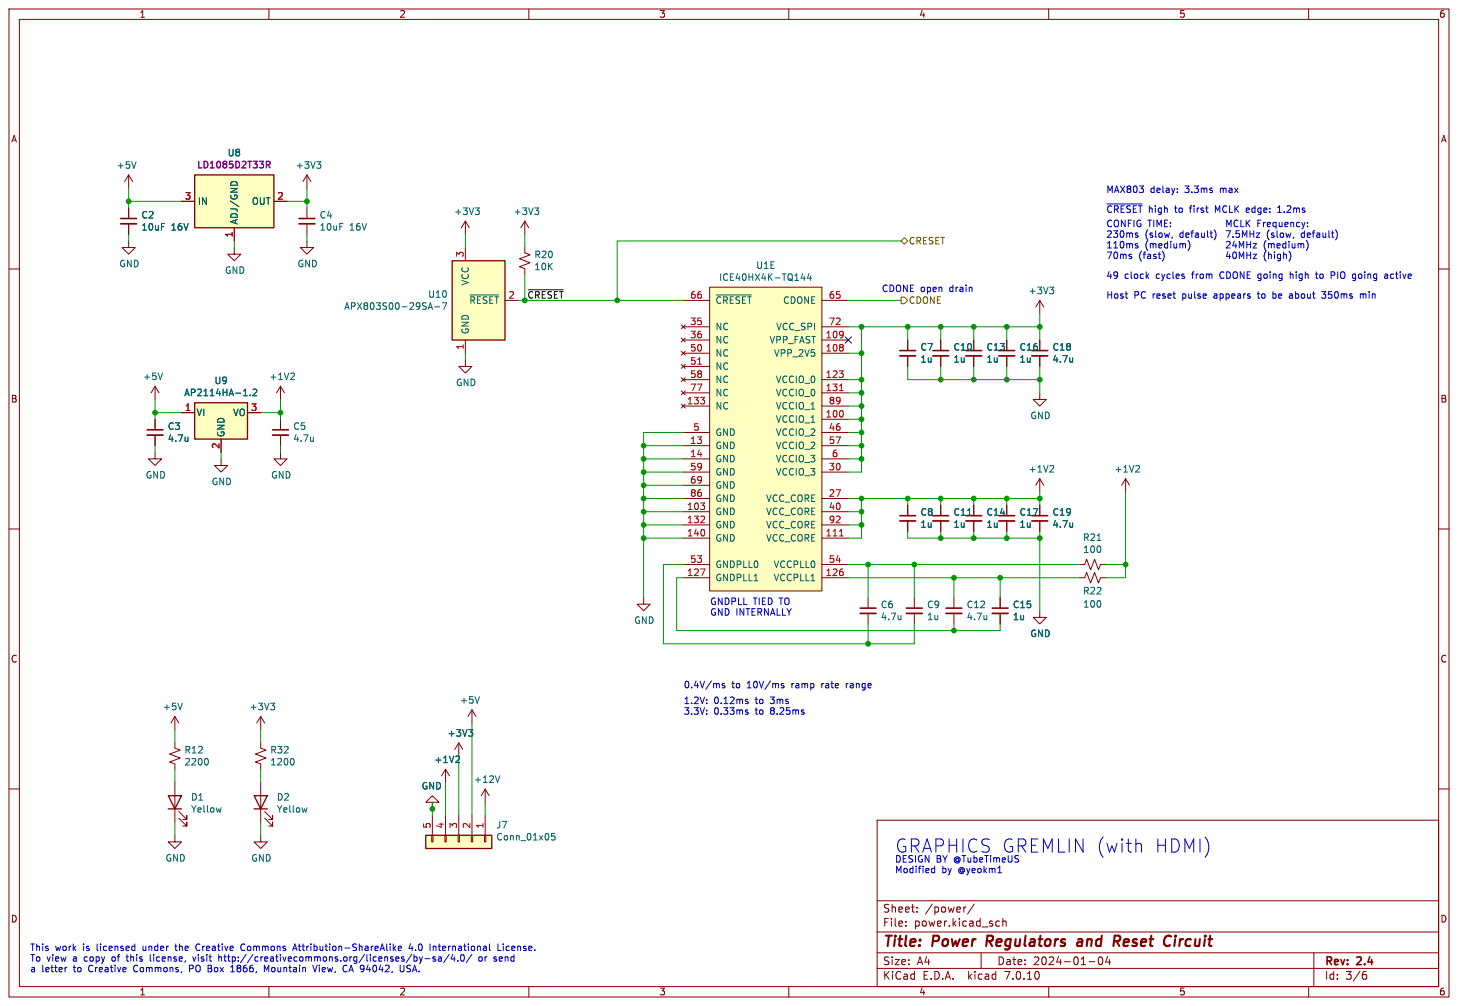
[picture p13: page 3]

CDONE open drain GRAPHICS GREMLIN (with HDMI)

Id: 3/6 Title: Power Regulators and Reset Circuit File: power.kicad_sch Sheet: /power/ R32

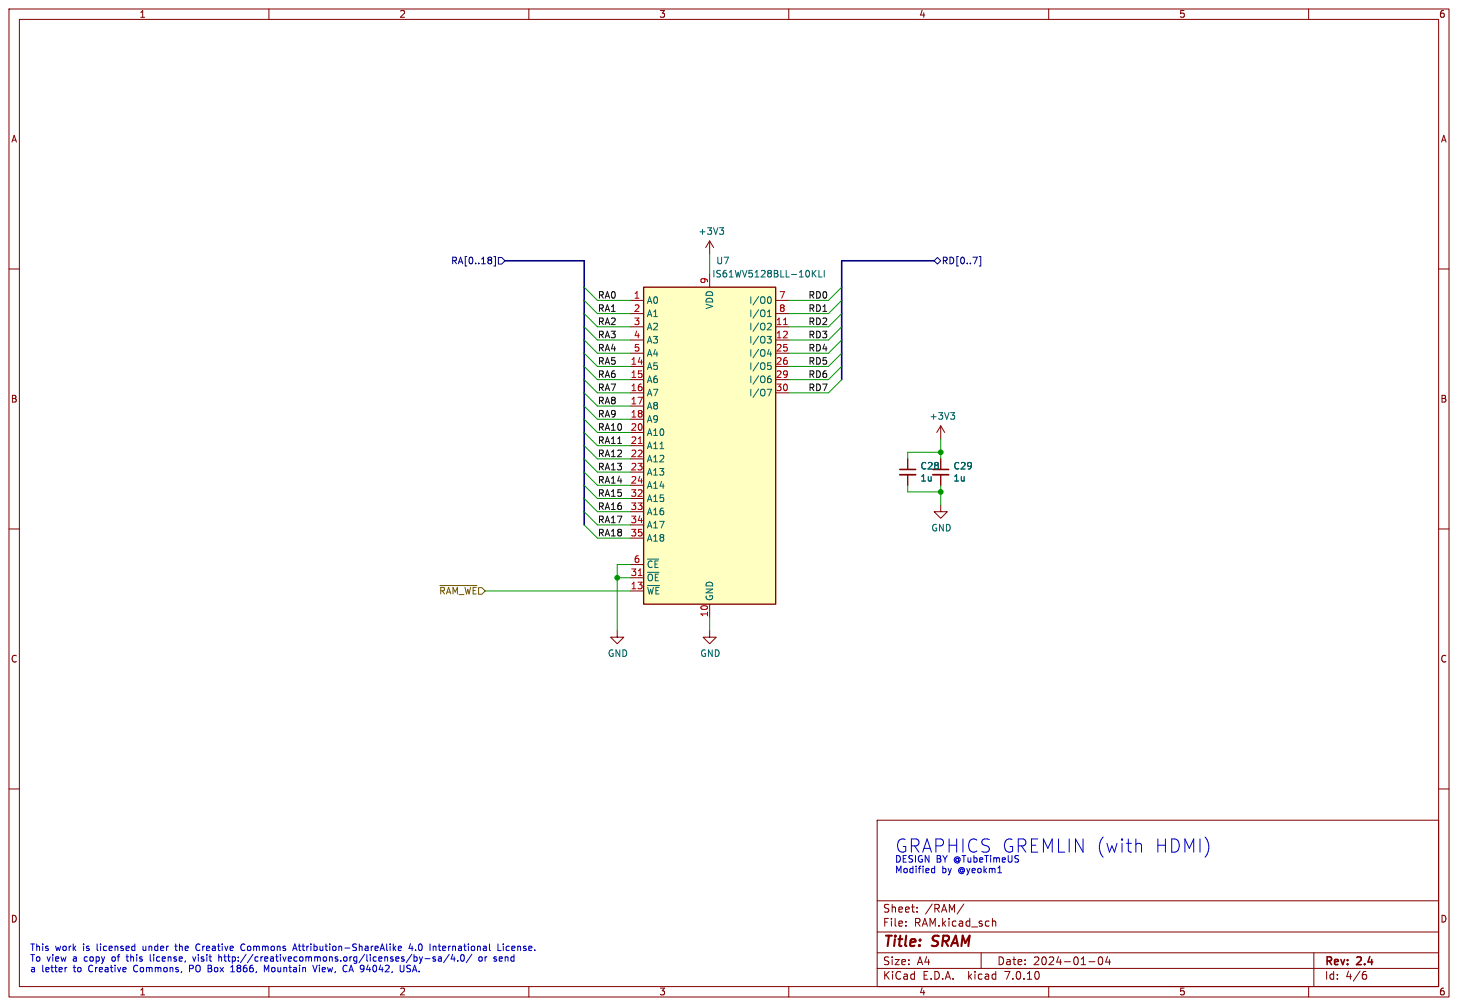
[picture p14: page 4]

File: RAM.kicad_sch Sheet: /RAM/
Id: 4/6 Title: SRAM

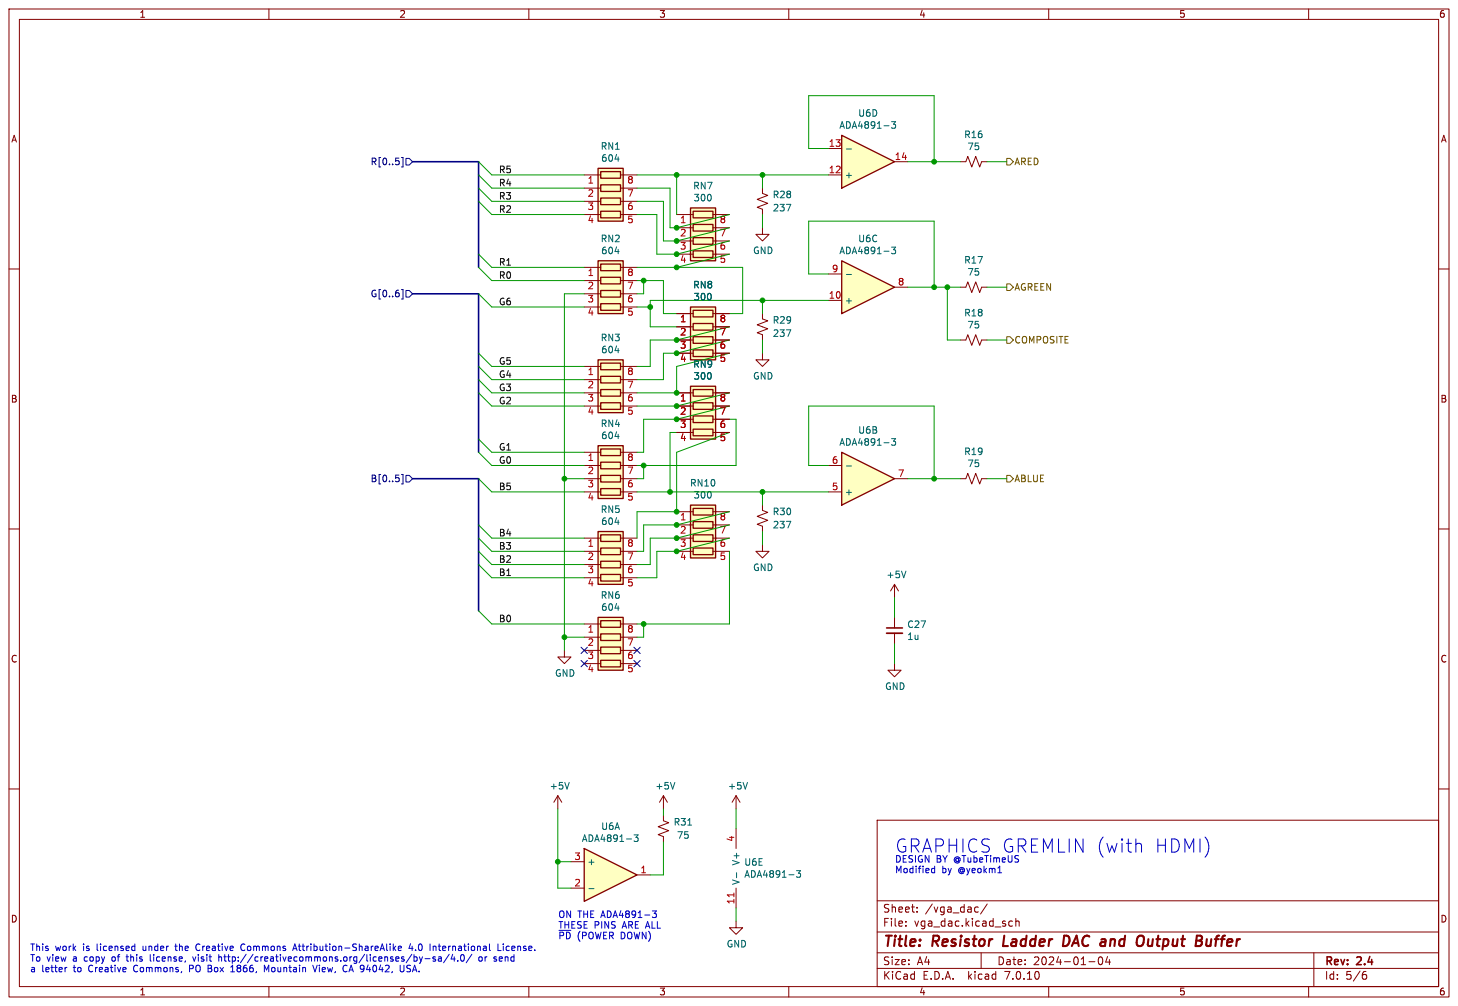
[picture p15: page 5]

Id: 5/6 Title: Resistor Ladder DAC and Output Buffer File: vga_dac.kicad_sch Sheet: /vga_dac/ R31

GRAPHICS GREMLIN (with HDMI)

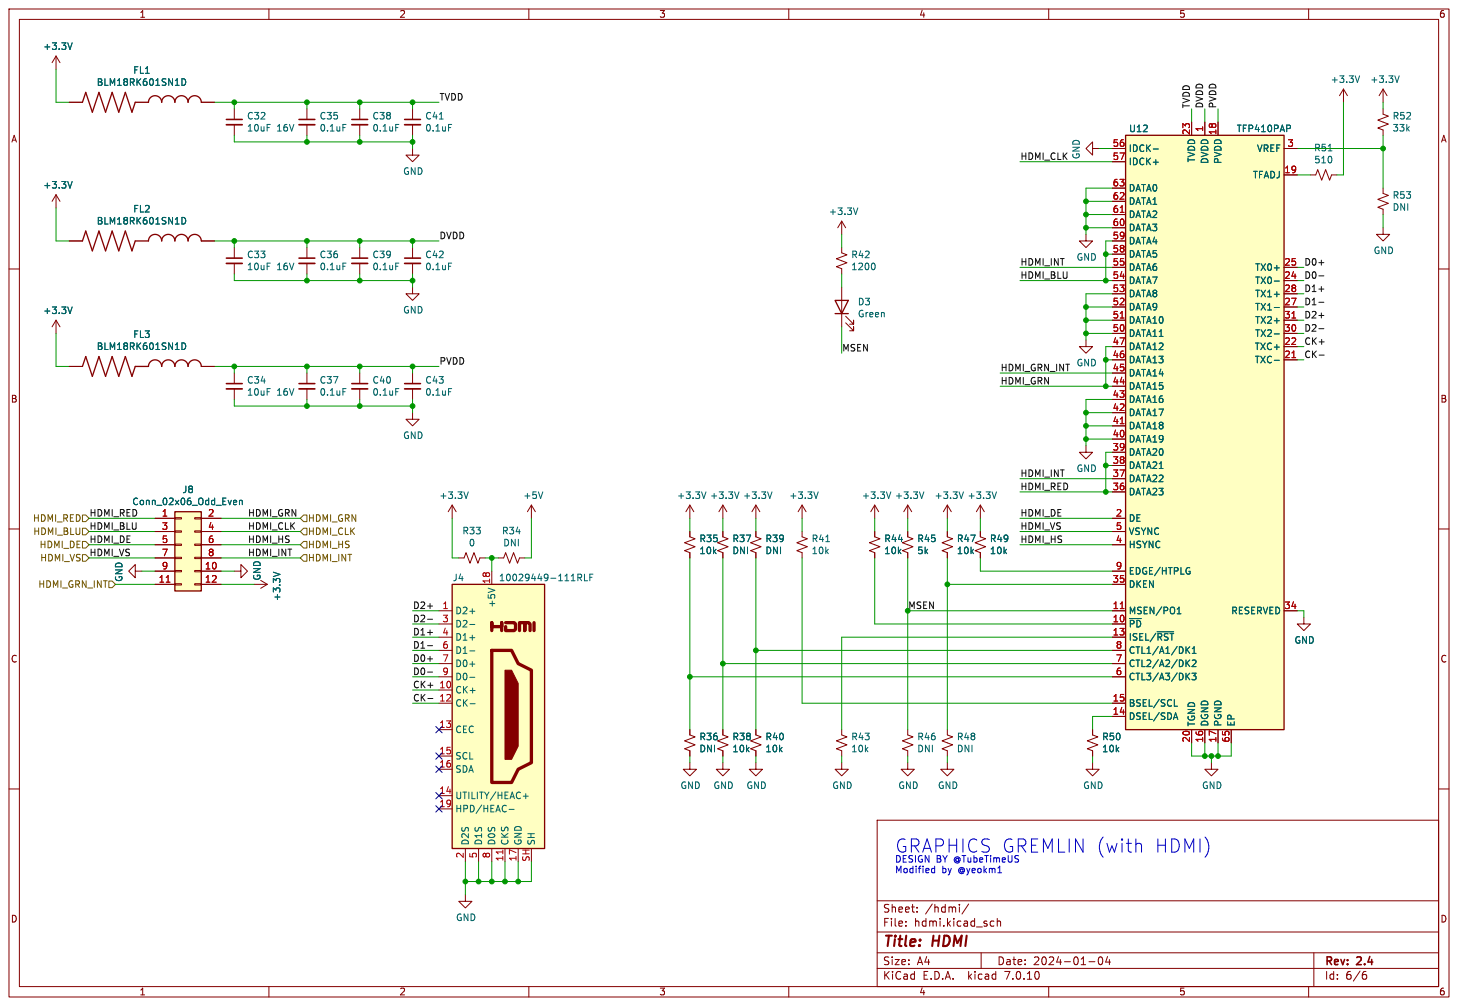
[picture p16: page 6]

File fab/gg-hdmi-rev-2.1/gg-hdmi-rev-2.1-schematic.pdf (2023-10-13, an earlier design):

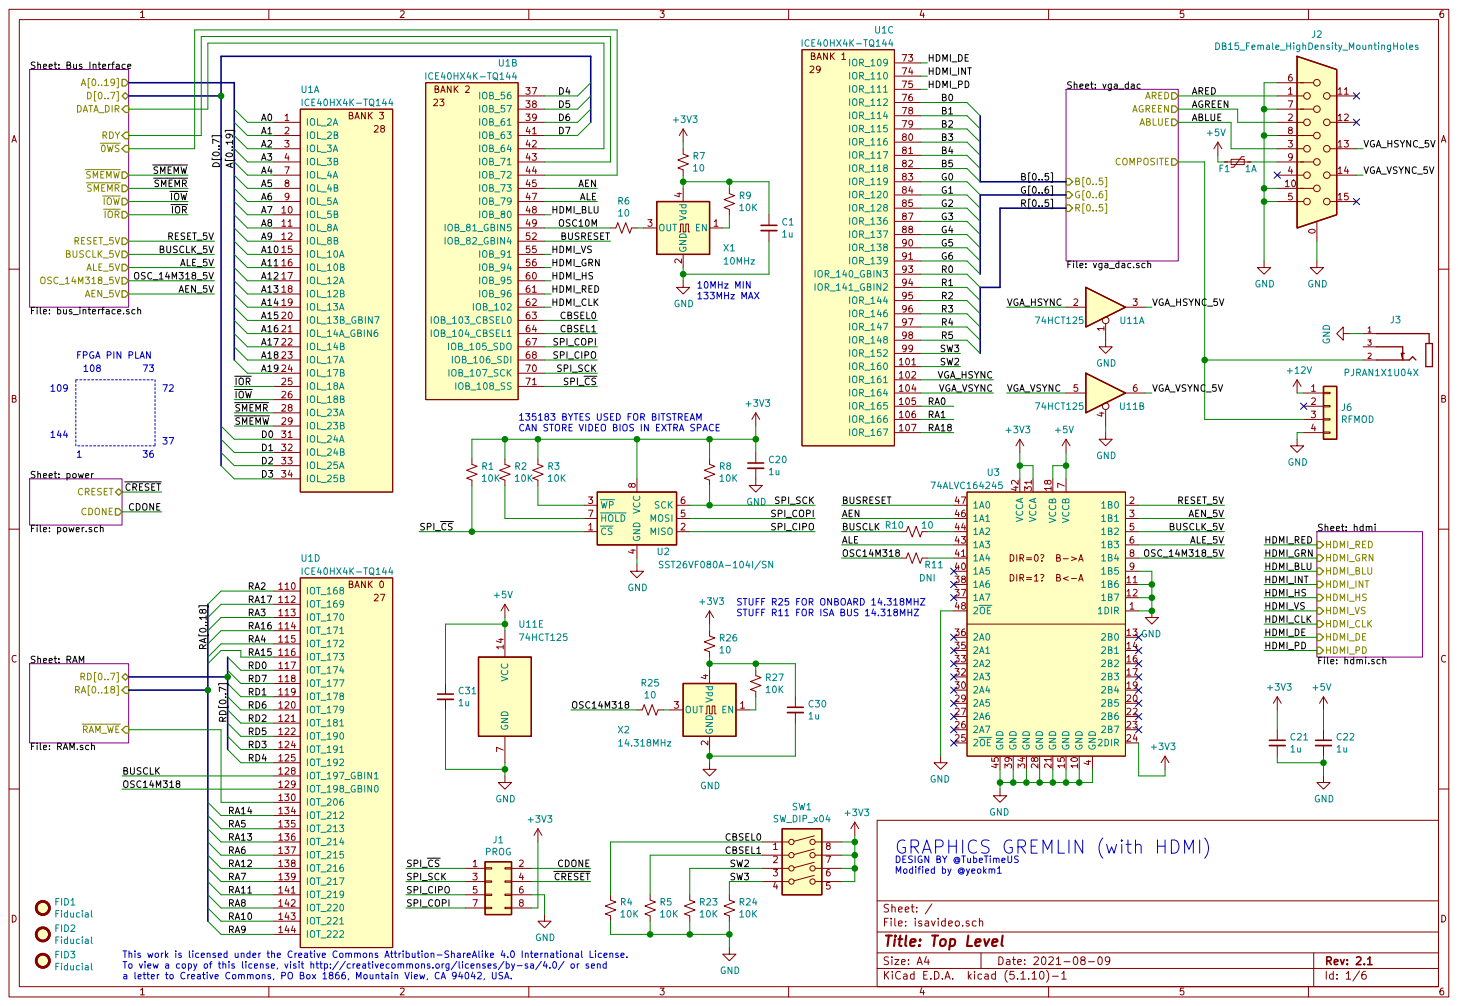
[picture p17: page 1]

108 FPGA PIN PLAN
File: power.schCDONE CRESET Sheet: RAM

4 MOSI 5 SCK 6 HOLD 7 VCC

IOT_198_GBIN0 129
IOT_206 130

GRAPHICS GREMLIN (with HDMI)

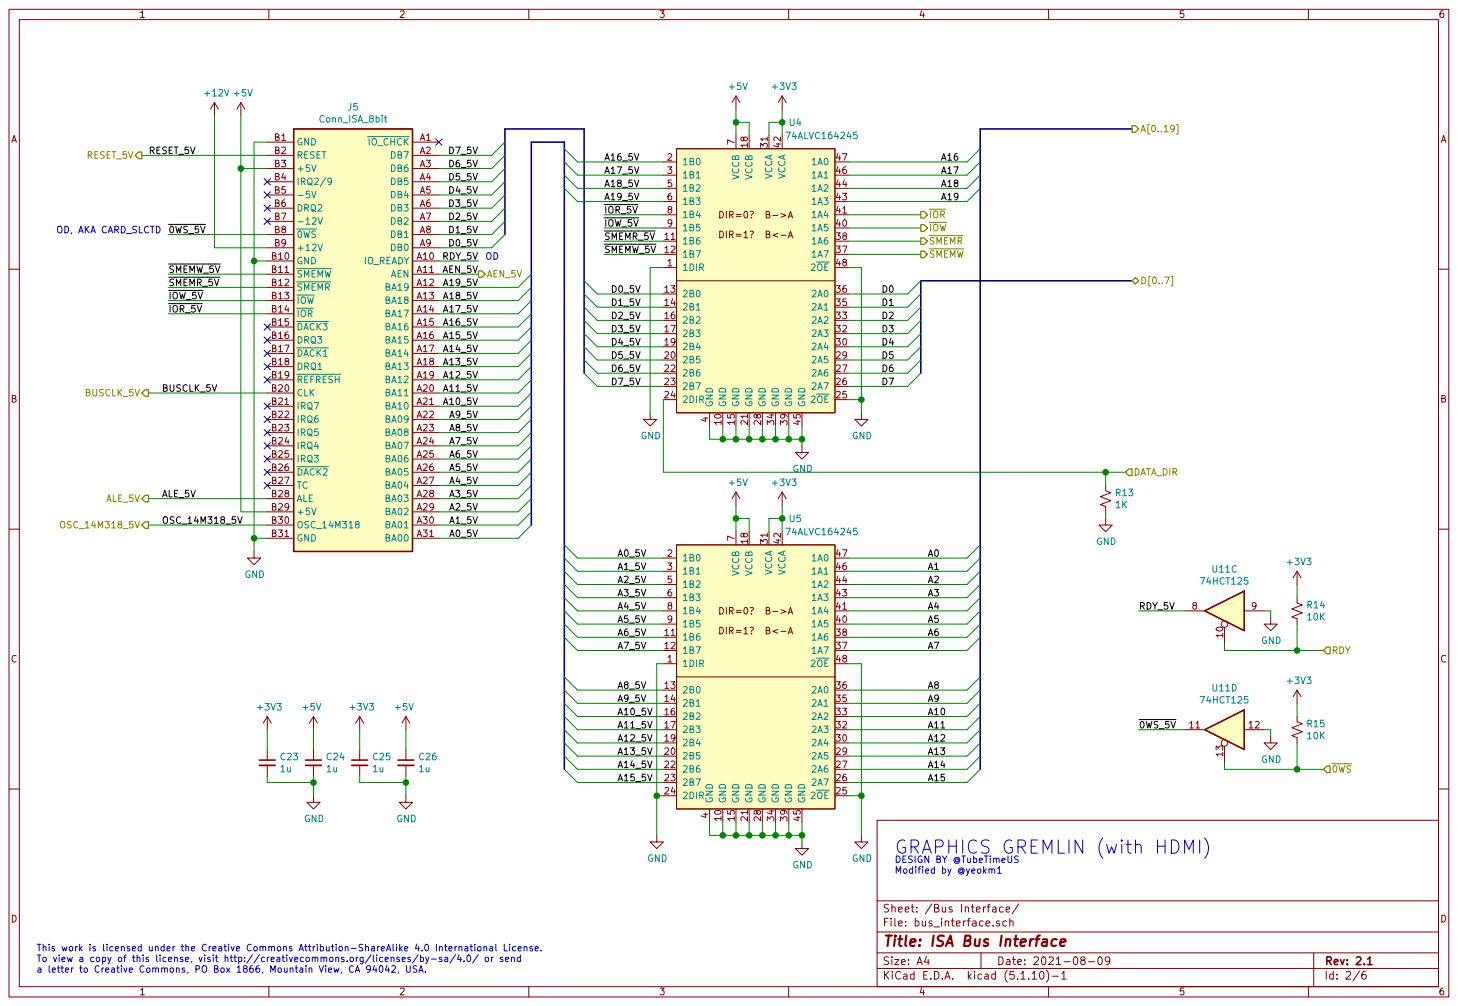
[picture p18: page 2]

GRAPHICS GREMLIN (with HDMI)
DESIGN BY @TubeTimeUS Modified by @yeokm1

Id: 2/6 Title: ISA Bus Interface

This work is licensed under the Creative Commons Attribution-ShareAlike 4.0 International License. To view a copy of this license, visit http://creativecommons.org/licenses/by-sa/4.0/ or send

a letter to Creative Commons, PO Box 1866, Mountain View, CA 94042, USA.

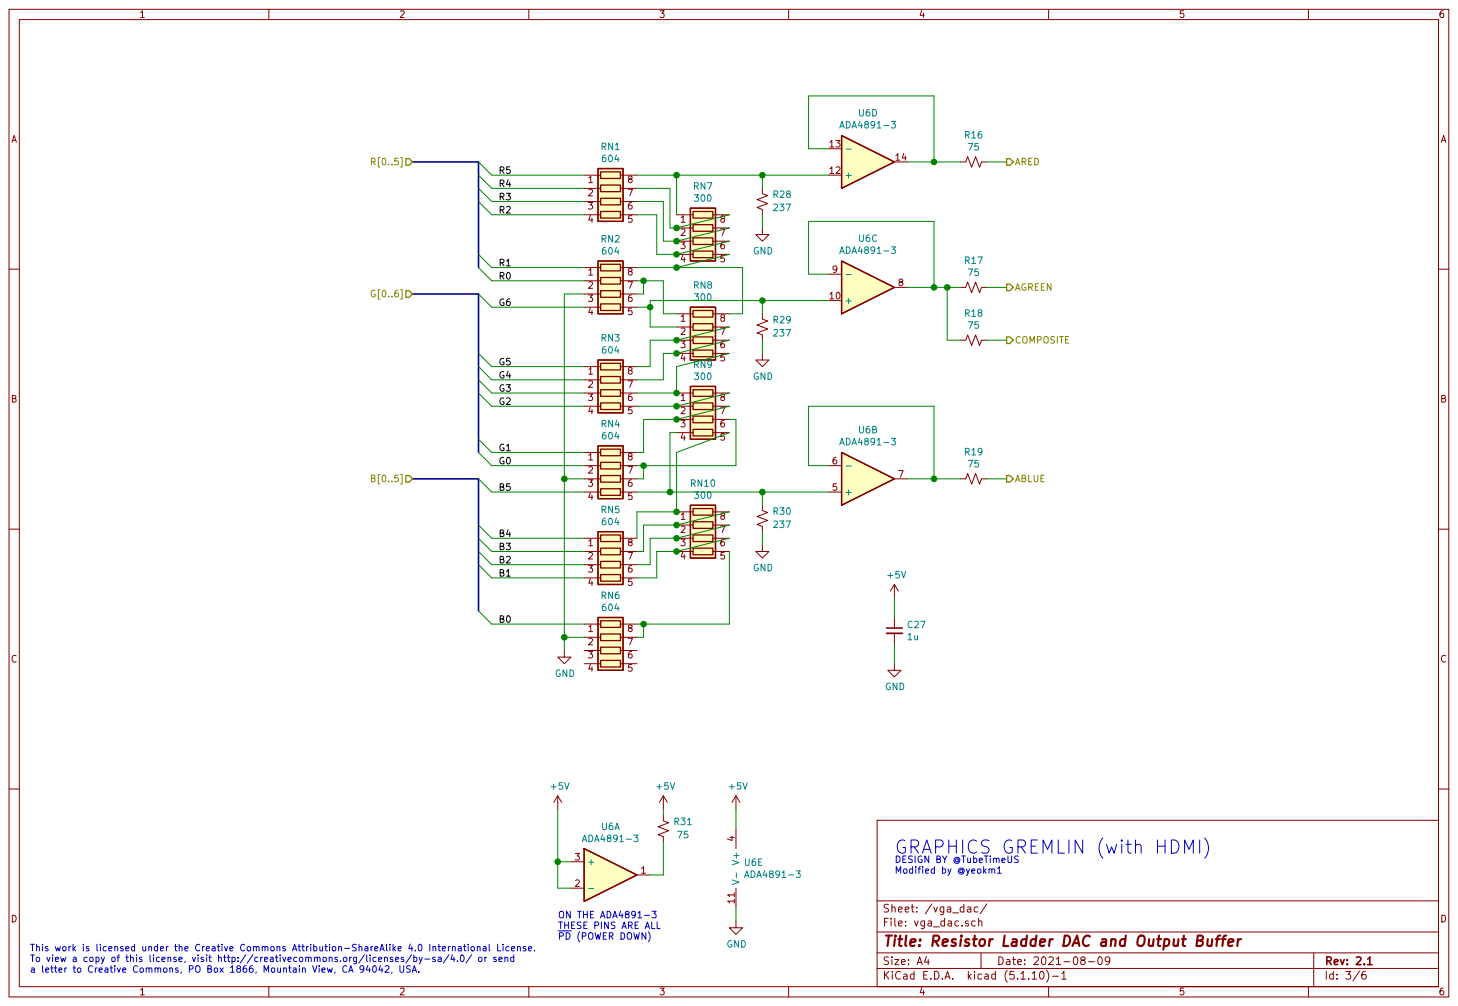
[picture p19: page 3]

ARED G4 R4 G3 G2 G1 G0 R2 R1 R0B4B3B2R5B1G6 R3 G5 B0B5 This work is licensed under the Creative Commons Attribution-ShareAlike 4.0 International License. To view a copy of this license, visit http://creativecommons.org/licenses/by-sa/4.0/ or send

GRAPHICS GREMLIN (with HDMI) ON THE ADA4891-3 THESE PINS ARE ALL PD (POWER DOWN)

Sheet: /vga_dac/
File: vga_dac.sch
Id: 3/6 Title: Resistor Ladder DAC and Output Buffer

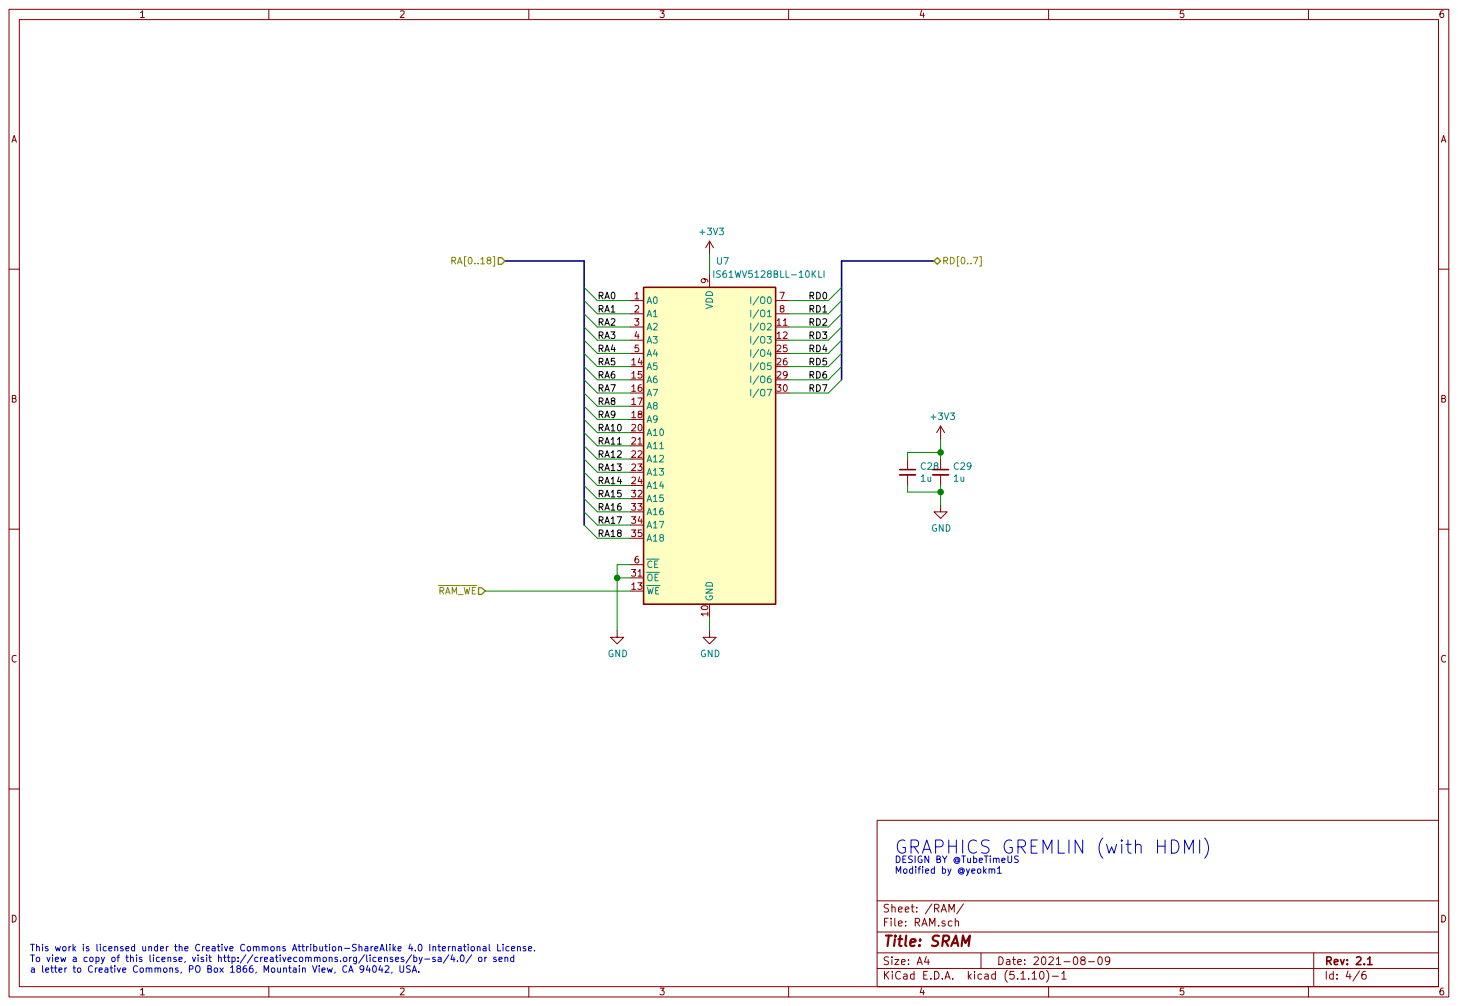
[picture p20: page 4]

File: RAM.sch Sheet: /RAM/
Id: 4/6 Title: SRAM

a letter to Creative Commons, PO Box 1866, Mountain View, CA 94042, USA.

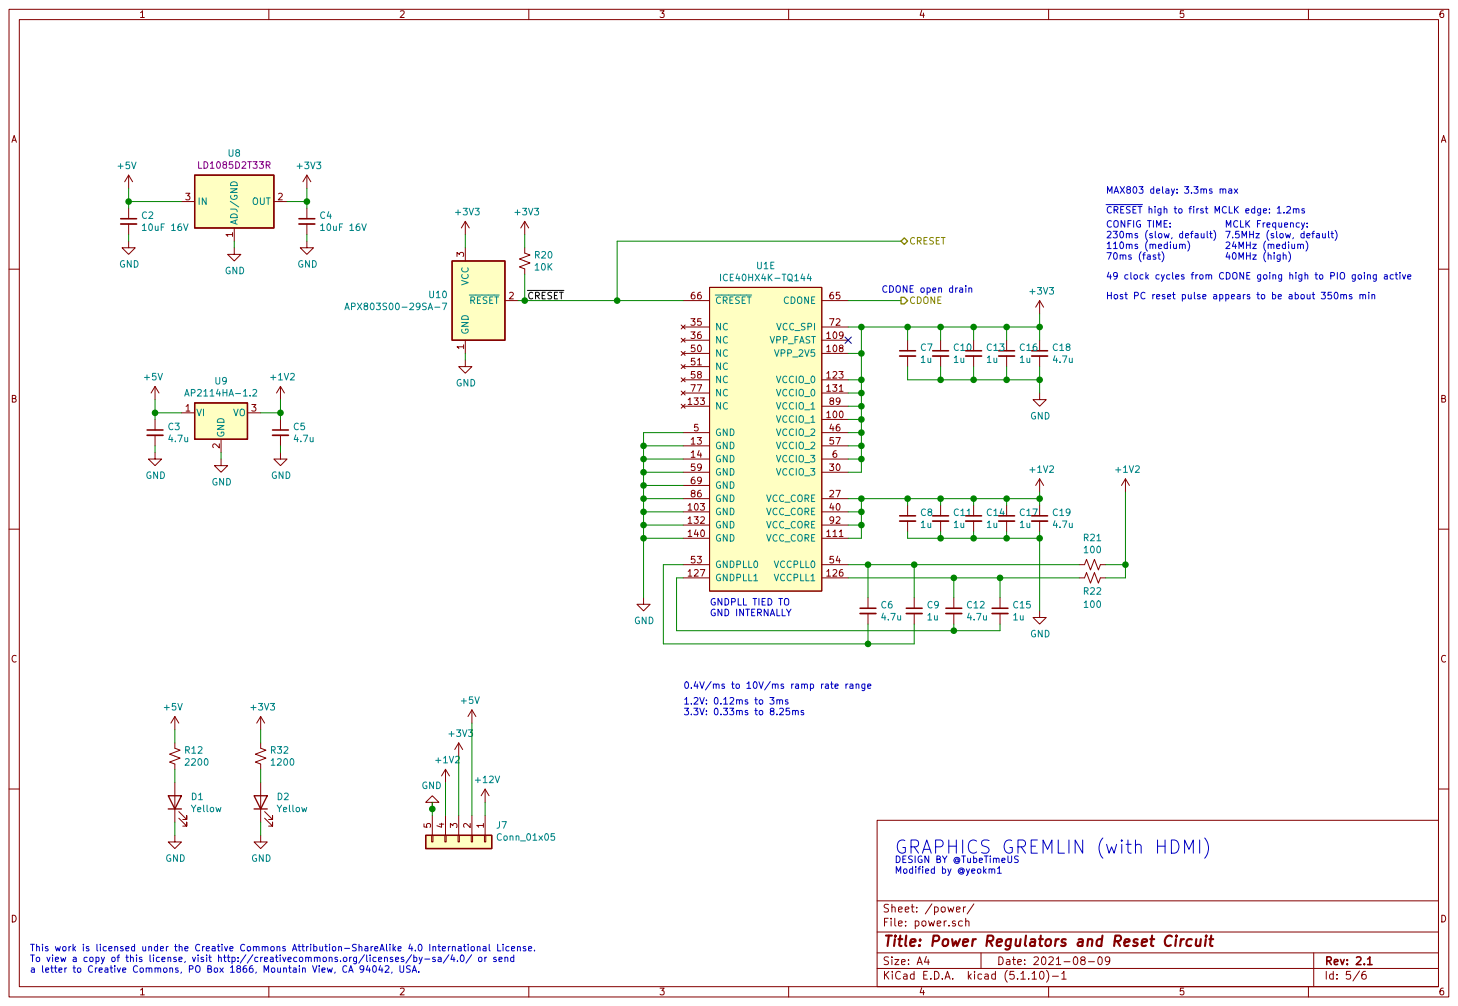
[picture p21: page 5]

+3V3 GND
49 clock cycles from CDONE going high to PIO going active GNDPLL TIED TO

CRESET high to first MCLK edge: 1.2ms

Host PC reset pulse appears to be about 350ms min

GRAPHICS GREMLIN (with HDMI)

File: power.sch
Id: 5/6 Title: Power Regulators and Reset Circuit

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

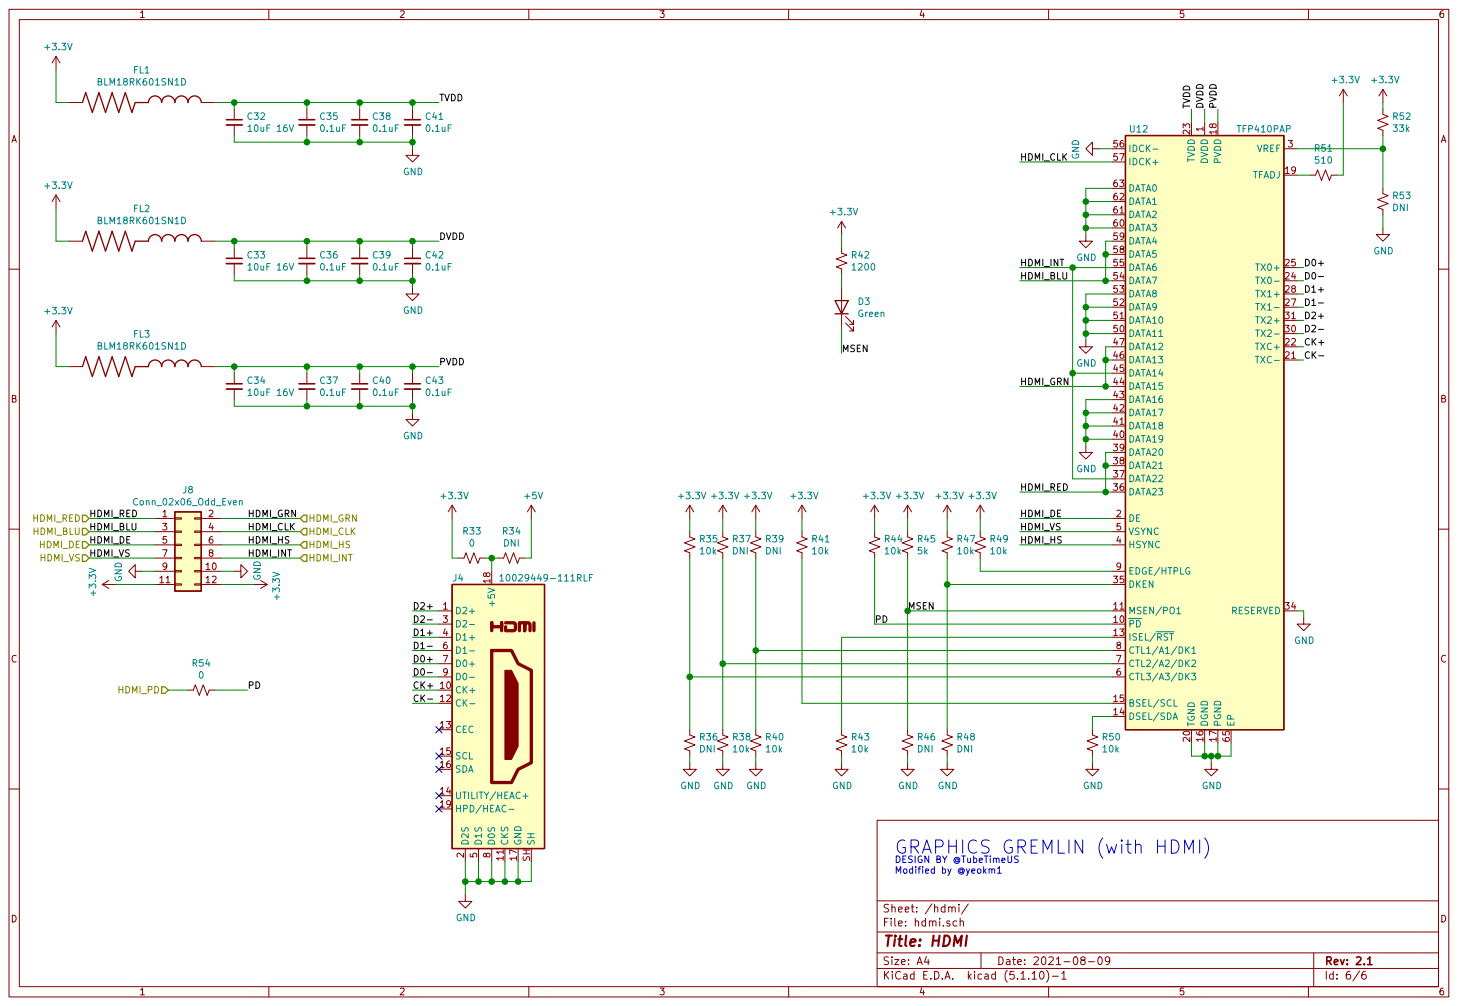
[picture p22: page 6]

HDMI_CLK GRAPHICS GREMLIN (with HDMI) DESIGN BY @TubeTimeUS Modified by @yeokm1

Id: 6/6 Title: HDMI File: hdmi.sch Sheet: /hdmi/

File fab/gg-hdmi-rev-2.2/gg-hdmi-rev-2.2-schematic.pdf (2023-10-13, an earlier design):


~{0WS} Bus Interface File: bus_interface.kicad_sch RD[0..7]
AEN_5V DATA_DIR

CAN STORE VIDEO BIOS IN EXTRA SPACE

4 MOSI 5 SCK 6 ~{HOLD} 7 VCC

GRAPHICS GREMLIN (with HDMI)

Id: 1/6 Title: Top Level File: isavideo.kicad_sch Sheet: /


GRAPHICS GREMLIN (with HDMI)
DESIGN BY @TubeTimeUS Modified by @yeokm1

Id: 2/6 Title: ISA Bus Interface

a letter to Creative Commons, PO Box 1866, Mountain View, CA 94042, USA.


CDONE open drain GRAPHICS GREMLIN (with HDMI)

Id: 3/6 Title: Power Regulators and Reset Circuit File: power.kicad_sch Sheet: /power/ R32


File: RAM.kicad_sch Sheet: /RAM/
Id: 4/6 Title: SRAM



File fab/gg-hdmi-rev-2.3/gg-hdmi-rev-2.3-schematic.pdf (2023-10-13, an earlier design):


File: RAM.kicad_sch CDONE CRESET

CAN STORE VIDEO BIOS IN EXTRA SPACE

4 MOSI 5 SCK 6 ~{HOLD} 7 VCC

GRAPHICS GREMLIN (with HDMI)


GRAPHICS GREMLIN (with HDMI)
DESIGN BY @TubeTimeUS Modified by @yeokm1

Id: 2/6 Title: ISA Bus Interface

a letter to Creative Commons, PO Box 1866, Mountain View, CA 94042, USA.


CDONE open drain GRAPHICS GREMLIN (with HDMI)

Id: 3/6 Title: Power Regulators and Reset Circuit File: power.kicad_sch Sheet: /power/ R32


File: RAM.kicad_sch Sheet: /RAM/
Id: 4/6 Title: SRAM



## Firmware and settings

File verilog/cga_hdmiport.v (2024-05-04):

module cga_hdmiport(
    input clk,
    input[3:0] video,
    input display_enable,

    input hsync,
    input vsync,

    output hdmi_red,
    output hdmi_grn,
    output hdmi_blu,
    output hdmi_int,
    output hdmi_grn_int,

    output hdmi_vs,
    output hdmi_hs,

    output hdmi_clk,

    output hdmi_de,

    );

    reg[0:0] prev_de;
    reg[0:0] prev_de2;
    reg[0:0] current_hs;
    reg[0:0] current_vs;
    reg[0:0] current_red;
    reg[0:0] current_blue;
    reg[0:0] current_grn;
    reg[0:0] current_grn_int;
    reg[0:0] current_de;

    always @(posedge clk)
    begin
        // Offset bug in image being shifted 2 pixels to the right.
        current_de <= prev_de;
        prev_de <= prev_de2;
        prev_de2 <= display_enable;

        current_vs <= vsync;
        current_hs <= hsync;

        current_red <= video[2];
        current_blu <= video[0];
        current_int <= video[3];

        // To generate brown value
        current_grn <= video[1] ^ (video[2] & video[1] & (video[0] ^ 1) & (video[3] ^ 1));
        current_grn_int <= video[3]^ (video[2] & video[1] & (video[0] ^ 1) & (video[3]^ 1));
    end


    assign hdmi_clk = clk;

    assign hdmi_de = current_de;

    assign hdmi_vs = current_vs;
    assign hdmi_hs = current_hs;

    assign hdmi_red = current_red;
    assign hdmi_blu = current_blu;
    assign hdmi_int = current_int;

    assign hdmi_grn = current_grn;
    assign hdmi_grn_int = current_grn_int;
    
endmodule

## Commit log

2023-10-13 Display CGA colour 6 brown in HDMI port (#2)
    [RAM.kicad_sch, bus_interface.kicad_sch, gg-hdmi-rev-2.1-bom.csv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]
2023-10-17 add gerbers
2024-01-24 V2.4 changes (#3)
    [RAM.kicad_sch, bus_interface.kicad_sch, gg-hdmi-rev-2.4-bom.csv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]
2024-02-16 add 3d bracket design
    [gg-hdmi-3d-bracket.stl, gg-hdmi-bracket.step]
2024-05-04 corrected CGA HDMI bug of image shifted one pixel right
    [cga_hdmiport.v]
2024-05-04 corrected shifted right by one pixel bug in MDA as well
    [mda_hdmiport.v]
2024-05-04 corrected colour offset issue.
    [cga_hdmiport.v]
2024-09-28 update image with metal bracket
